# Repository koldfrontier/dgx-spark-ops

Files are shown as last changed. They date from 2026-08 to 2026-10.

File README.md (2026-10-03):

# dgx-spark-ops

Assets, designs and operational notes for running **NVIDIA DGX Spark** / **ASUS Ascent GX10**
desktop AI machines.

## Contents

| Path | What it is |
|---|---|
| [`design/cooling-cage`](design/cooling-cage) | Screwless 3D-printed active-cooling cage for two units, with three 120 mm fans. Print files, CAD source, and a full assembly guide. |
| [`recipes`](recipes) | Reproducible multi-node inference serving configs — launch scripts, boot profiles, tuning data, and honest trust/security notes for specific model checkpoints. Two-, three- and four-node. |
| [`notes`](notes) | Operational findings that outlive any one model: running four Sparks as a switchless RoCE ring, what the topology costs, the failure modes that look like a healthy container, and the re-cabling trap that silently costs a GB10 7/8 of its RDMA bandwidth. |

More to follow.

## Licensing

Code and text in this repository are **Apache-2.0** (see [`LICENSE`](LICENSE)).

3D models are licensed separately as **CC BY 4.0** — see the `LICENSE-CC-BY-4.0.txt` file
alongside the model in question. In short: use, remix and sell derivatives freely, just credit
the source.

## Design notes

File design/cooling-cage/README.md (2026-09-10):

# DGX Spark Dual Cooler

A screwless, 3D-printed active-cooling cage that holds **two DGX Spark / ASUS Ascent GX10**
units on edge and drives three 120 mm fans through them.

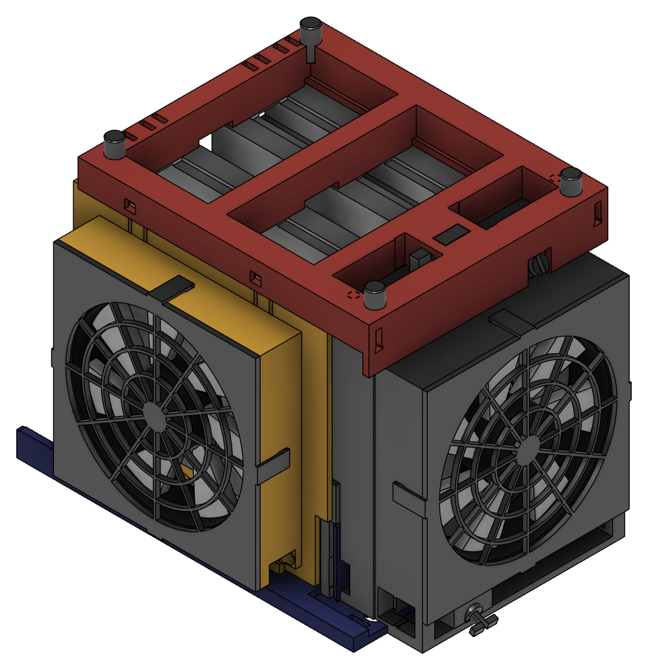
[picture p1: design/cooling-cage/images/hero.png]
Assembled cage


There is not a single screw, heat-set insert or drop of glue in the assembly. Everything
slides into a dovetail, snaps into a latch, clips over a hook, or is locked by one printed
wedge key.

| | |
|---|---|
| Fans | 3 × 120 mm |
| Fasteners | none |
| Assembled size | 206 x 253 x 190 mm |
| Filament | ~580 g PETG at 20 % infill (estimate) |
| Printed parts | 15 (10 unique) |
| Bed needed | 248 × 250 mm (largest part is 176 × 220 mm) |
| Supports | needed on the arm and the plenum; none on the other eight parts |

## How it works

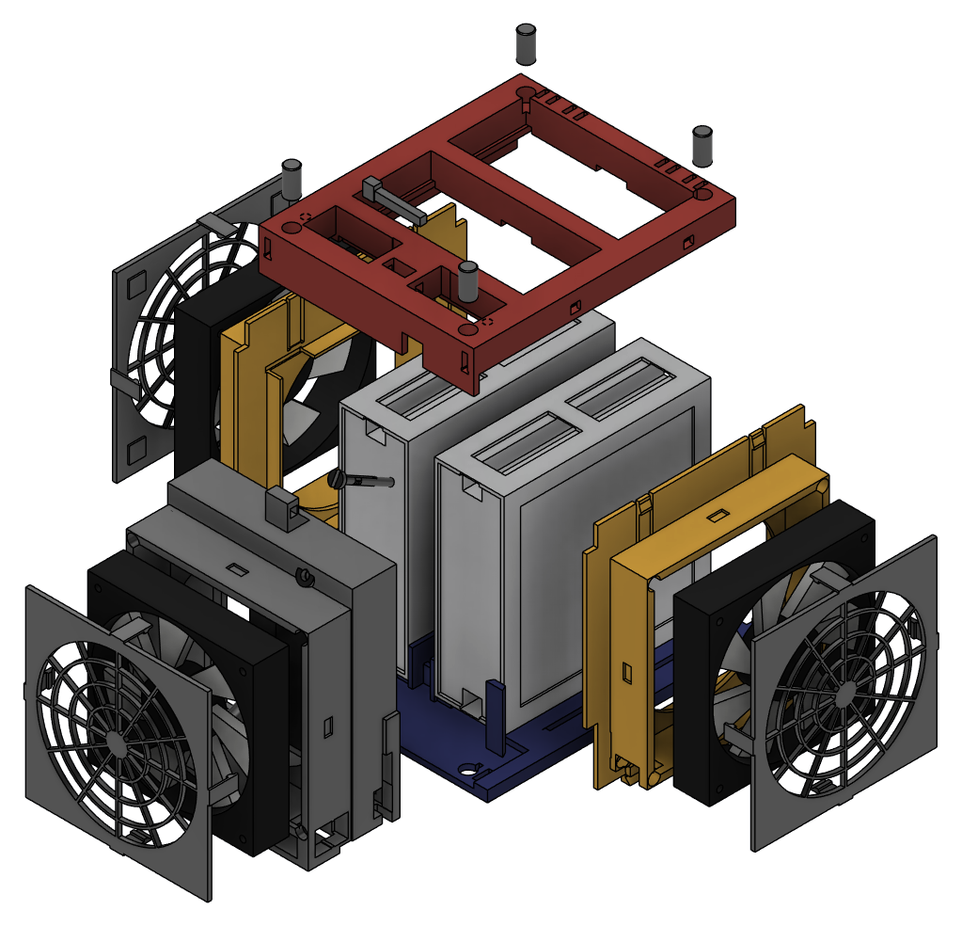
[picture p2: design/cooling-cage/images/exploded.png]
Exploded view


The two units stand on edge and are **mirrored** — one is flipped end-for-end so both filtered
bottom panels face outward into the side fans. Combined width is 50.5 + 19 + 50.5 = 120 mm,
exactly one fan frame.

- **Two side fans** blow inward through each unit's filtered bottom panel.
- **One front fan** pressurises a sealed plenum feeding both front intakes, plus a centre duct
  with two ram scoops that jets air down the 19 mm gap between the units.
- Everything exhausts out the rear, which is deliberately left clear for the port strips, the
  QSFP stacking cable and a future exhaust attachment.

A consequence of mirroring is that one unit's power button ends up near the top of its front
face and the other near the bottom — hence two different captive push-pins.

## Bill of materials

### Printed

| Part | Qty | Size mm | Print orientation | Support |
|---|---|---|---|---|
| `01-base-tray` | 1 | 176 × 220 × 46 | as exported | none |
| `02-front-plenum` | 1 | 139 × 180 × 66 | as exported (back plate down) | **yes** |
| `03-side-fan-arm` | 2 | 171.6 × 166 × 39.6 | as exported (fan collar up) | **yes** |
| `04-top-brace` | 1 | 156 × 190 × 30 | as exported | none |
| `05b-fan-grille-25mm` | 3 | 135 × 135 × 21 | as exported | none |
| `05-fan-grille-26mm` | 3 | 135 × 135 × 21 | as exported | none |
| `06-wedge-key` | 1 | 10 × 6 × 41 | as exported | none |
| `07-stacking-peg` | 4 | Ø10 × 20 | as exported | none |
| `08-button-pin-long` | 1 | 15 × 30.5 × 72.5 | as exported | none |
| `09-button-pin-short` | 1 | 10 × 10 × 46 | as exported | none |

Every STL and the 3MF are already **in their correct print orientation, sitting on Z = 0**.
Drop them in and slice — do not rotate.

**Print only one grille variant.** `05b` has 2.2 mm clamp pads for **25 mm** thick fans;
`05` has 1.2 mm pads for **26 mm** fans. The pads preload the fan against its sealing land, so
the wrong variant leaves the fan loose and buzzing.

### Bought

| Item | Qty | Notes |
|---|---|---|
| 120 mm fan | 3 | Tested with Thermalright TL-C12C (25 mm, 4-pin PWM, ASIN `B0BN19KSW2`, sold as a 3-pack) and NZXT F120 (26 mm). Any standard 120 × 120 fan with a 105 mm hole pitch fits. |
| Fan speed controller | 1 | Wathai 36 W, 110–240 V AC → 4–12 V DC 3 A with a 4-port splitter (ASIN `B0F4KG6MM1`). Voltage control, so all the heat stays in the external brick. Three fans draw ~0.6 A of 3 A. |
| Zip ties | ~8 | 2.5 × 100 mm, for the cable channels |

## Print settings

- **PETG.** Every latch, hook and pin leg is a printed spring; the strain figures assume
  E ≈ 2000 MPa. PLA will work but is more brittle at the flexures.
- **0.4 mm nozzle, 0.2 mm layers.**
- **4 perimeters minimum.** Thin walls halve the strength of every snap feature.
- **20 % infill** is plenty. Nothing is structural beyond the flexures.
- **Supports on for `02-front-plenum` and `03-side-fan-arm`, off for everything else.** Both of
  those parts carry a large flat panel that starts in mid-air, and neither has an orientation
  that avoids it — see [`docs/printability-analysis.md`](docs/printability-analysis.md) for the
  measurements and the six-orientation sweep. Tree supports on the arm's plate underside are
  enough; the plenum wants normal supports under its front face.
- **No brim needed.** The long button pin prints on a 15 × 30.5 mm footprint at 72.5 mm tall.

> An earlier version of this README claimed no part needed support. That was wrong: the v2
> shroud collar removed the arm's only support-free orientation, and the reach figures behind
> the claim did not survive re-measurement. The two large parts need support.

## Fitting the GX10's rubber feet

Foot clearance notches

The GX10 has four rubber feet on its bottom panel, and that panel is the face that looks
outward into the side fans — so the feet land on the shroud collar. The collar's top wall is
notched at both ends to clear them: the top wall runs only over the middle of the span, and the
two end sections are open.

If you are printing from the current files this is already done. If you have arms printed from
an earlier release, cut the top wall away from each collar corner to the far edge of the latch
snap on both sides, at both ends of both arms.

The foot dimensions were never measured — the notch is sized from the collar geometry with
deliberate margin. If a foot still fouls, open an issue with the foot diameter, height and
centre positions.

## Assembly

Full illustrated instructions: **[docs/assembly-guide.pdf](docs/assembly-guide.pdf)** (10 pages).

The short version:

1. Set down the base tray, front edge toward you.
2. Slide both side fan arms in **from the rear** along the 45° dovetails, ~150 mm.
3. Drop the front plenum onto the two dovetail posts.
4. Lower in the two units, mirrored. Connect the QSFP cable now.
5. Push the three fans into their collars from outside — side fans blow **in**, front fan blows
   **rearward**.
6. Clip the three grilles on: line up four hooks each, press until they click (~11 N).
7. Drop the top brace on — the arm latches snap near the end of travel — then tap the wedge key
   home through the bridge and the plenum tenon.
8. Press in the four stacking pegs and snap the two button pins into their tubes.

Teardown is the reverse: drive the key out, release both arm latches, lift the brace.

To swap a fan later, pry off that grille only. Nothing else has to come apart.

## Cable routing

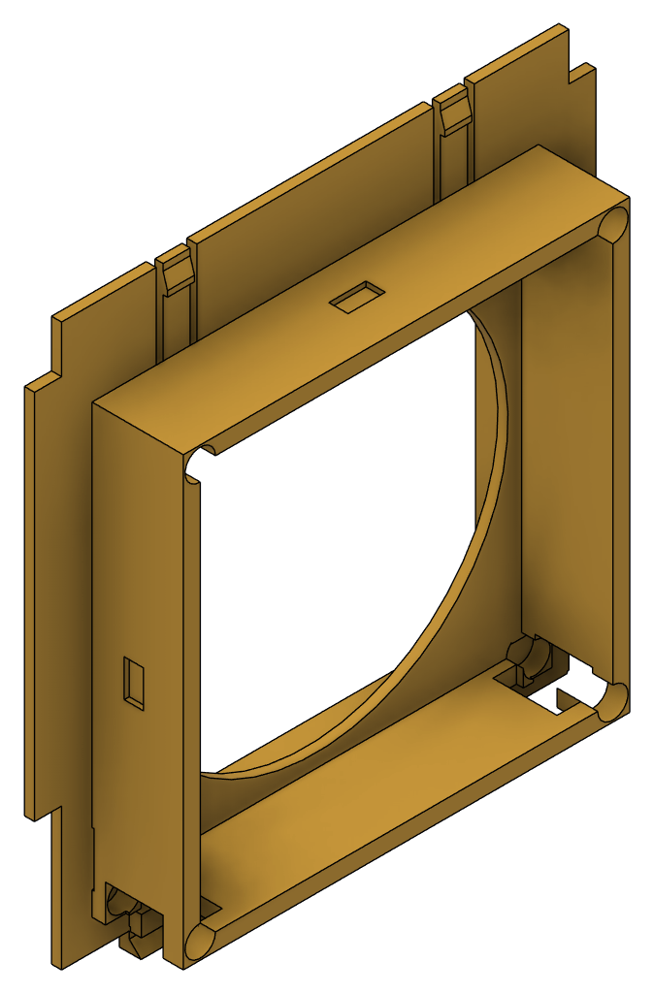
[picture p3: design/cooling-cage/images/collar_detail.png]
Cable routing


All three fan leads run inside the cage and exit together at the rear. Each fan pocket has all
four corners relieved, so whichever corner the lead exits it has a channel; it drops through a
floor exit into the tunnel between the tray ear and the arm collar, then runs rearward through a
gland and out the back of the tray. The front fan's lead exits a side window in the plenum skirt
and joins the same tunnel.

Every restriction on that route passes a 14 × 8 mm fan connector: the arm cable windows are
16.5 × 10.0 mm, the plenum skirt windows 21.5 × 10.0 mm per side, the plenum rear slot
10.5 × 16.5 mm per side, and the fan-pocket floor slots 15.5 mm (arm) and 14.3 mm (plenum).

The run sits entirely outboard of the exhaust footprint and below the port strip, so nothing is
in the hot stream and nothing crosses the rear ports.

**If you add your own bracket to the rear ears, keep it under 17 mm tall** — the arm collar
sweeps that band during assembly, and anything taller makes the arms impossible to fit or remove.

## Files

```
cad/    dgx-spark-cooling-cage.f3d     Fusion source, fully parametric
        dgx-spark-cooling-cage.step    STEP AP214, for any other CAD
print/  dgx-spark-cooling-cage.3mf     all parts, grouped by print plate
        stl/*.stl                      one file per part, print-oriented
docs/   assembly-guide.pdf             10-page illustrated guide
        design-notes.md                engineering rationale and verification
        printability-analysis.md       orientation and support measurements
        v2-tolerance-analysis.md       what the first print got wrong, and by how much
images/                                renders used above
```

The 3MF groups parts into eleven plates. Standard 3MF has no plate concept, so slicers will show
all objects at once laid out in a grid — use "arrange all" or assign plates by hand. The intended
grouping is in `design-notes.md`.

## Status

**v3 — v2's faults fixed in CAD, still unprinted.** The v1 design was printed and assembled;
four problems showed up that CAD had not caught, and all four are fixed:

- the button pin could not be inserted at all (the barb was a full ring that squeezing could not
  shrink — a geometric impossibility, not a tolerance issue)
- the arm latches could not be released (the access window was aimed 1.5 mm above the barb)
- air bypassed the units through a 10 mm gap around each fan discharge
- the units slid side to side, unconstrained outboard above z = 8

Then two more that only turned up later:

- the GX10's rubber feet fouled the shroud collar — the reference model has no feet, so CAD
  never saw it. Notched, see above.
- the collar left the arm with no support-free print orientation, and the plenum had been
  re-oriented onto a worse one. Both re-measured, the plenum re-exported, and the support
  claim in this README corrected.

See [`docs/v2-tolerance-analysis.md`](docs/v2-tolerance-analysis.md) for the measurements behind
the first four fixes. Interference, assembly paths, printability and mesh quality are all
re-verified against the current solids; **nothing since v1 has been printed.**

Two known defects are open: `08-button-pin-long.stl` and `09-button-pin-short.stl` are
non-manifold (a handful of edges shared by four and six faces), which slicers will silently
repair in their own way. The B-reps have not been checked yet.

## License

Models (`cad/`, `print/`, `images/`): **CC BY 4.0** — see
[`LICENSE-CC-BY-4.0.txt`](LICENSE-CC-BY-4.0.txt).
Documentation and code: **Apache-2.0**, per the repository root.

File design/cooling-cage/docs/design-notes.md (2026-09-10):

# Design notes

Engineering rationale, the numbers behind the snap features, and how the design was verified.
Model v33. Everything here was measured against the solid model in Fusion.

**v1 was printed and assembled. Nothing since v1 has been printed** — every figure below for v2
and later is CAD verification, not experience.

## Thermal concept

The units are metal-shelled passive heat spreaders with two internal blowers exhausting rearward,
plus filtered intakes along both long edges of the front face and a filtered intake in the bottom
panel. Standing them on edge exposes the bottom panel to a side fan, which is the largest single
intake either unit has.

- Two side fans blow inward through each unit's filtered bottom panel.
- The front fan pressurises a sealed plenum. Its Ø114 throat opens into the plenum through a 45°
  diffuser chamfer, and two mouth windows feed the units' front intakes.
- A hollow centre duct in the 19 mm gap between the units takes air from two ram scoops sited at
  r = 38–58 mm from the fan axis — inside the blade annulus, clear of the Ø42 hub wake — and
  exits through two 3 × 112 mm slots that jet down each hot inner panel.

The centre duct is a calculated design, not a measured one. Its two exit slots are tapeable, so
an A/B test is easy: tape them, run the same load, compare.

## Fastening

Nothing is screwed. Five mechanisms carry the whole assembly.

| Joint | Mechanism | Numbers |
|---|---|---|
| Arm → tray | 45° half-dovetail, slides in from the rear | 0.12 mm clearance both flanks, 150 mm travel, hard stop at the front |
| Arm → brace | Two cantilever latch barbs into catch pockets | 1.30 mm barb, 0.63 % strain at release, 4.6 N per latch to release, 0.90 mm retained engagement |
| Grille → collar | Four cantilever hooks, 18 × 1.3 × 10 mm, 1.5 mm barb | 1.08 % strain, 2.8 N per hook, ~11 N to click on |
| Plenum → brace | Tusk tenon through a mortise, locked by a wedge key | 0.65 mm of taper available for tightening |
| Button pin → tube | Split shaft, two spring legs, two-pad snap barb | 0.45 mm squeeze needed against 1.20 mm available |

PETG at E ≈ 2000 MPa throughout. Repeated-use strain allowance for PETG is roughly 1.5–2 %, so
every flexure has at least 1.5× margin.

The dovetail clearance, the latch geometry and the pin barb are all v2 values. What they replaced
and why is in [`v2-tolerance-analysis.md`](v2-tolerance-analysis.md) — the v1 pin could not be
inserted at any force, and the v1 latch could not be released at all.

### Button pins

Each unit's front power button is behind the plenum, so each gets a captive printed push-pin
running in a guided tube. Bore profile:

| Distance from mouth | Bore radius | Enclosed |
|---|---|---|
| −0.5 → 2.5 mm | 2.90 mm, with a 38° lead-in funnel | yes |
| 3.0 → 14.0 mm | 4.00 mm (detent chamber) | yes |
| 14.5 mm → end | 2.70 mm | yes |

The barb is **two pads on the outer face of each leg**, limited to |v| ≤ 0.80 mm and crowning at
r = 3.35 — not a revolved ring. That distinction is the whole point: squeezing the legs translates
each half toward the centreline, which retracts material lying along the squeeze axis and does
nothing to material 90° away. A ring cannot be squeezed through its own bore; two pads can.

With the legs fully closed the barb envelope measures 2.159 mm against a 2.90 mm mouth. Required
squeeze is 0.45 mm of the 1.20 mm available, and on a tight printer ≈0.73 mm of 1.10 mm.

Long pin: 20.5° off the button axis, 6.0 mm free stroke, presses at +2.50 mm.
Short pin: 28.7° off axis, 5.0 mm free stroke, presses at +2.25 mm.

## Holding the units still

Each unit is a 150 mm slab. Three constraints hold it:

| Constraint | Position | Where it bears |
|---|---|---|
| Inboard | x = 9.5 (tray centre wall) | z 6–30 |
| Outboard | x = 60.4 (arm shroud collar frame) | y 13.0–15.5 and 135.0–137.5, z 21.0–23.5 and 143.0–145.5 |
| Top corners | x = 60.4 (brace capture ribs) | z 152–158 |

```
left-right play = 60.4 - 9.5 - 50.5 = 0.40 mm
```

Before v2 the outboard face was unconstrained above z = 8 and the unit could slide the full gap
to the arm plate. The shroud collar does double duty here: it is primarily an air seal, and the
lateral datum falls out of it for free.

The collar also cut bypass around each fan discharge from 3 580 mm² to 143 mm², a 96 % reduction.
And it is the reason the arm no longer has a support-free print orientation — see below.

## Clearance for the unit's feet

The GX10 has four rubber feet on its bottom panel, which is the face that looks outward into the
side fans, so the feet land on the collar. The collar's top wall sits 18-20 mm in from the panel
edge while the bottom and side walls sit at 13-15 mm; the feet fall in that 5 mm band and foul
only the top.

The top wall is therefore cut away at both ends, leaving it over y 38.0–112.0 only, mirrored
about y = 75 so both arms clear at both ends. The reference model of the unit has no feet
modelled, which is why interference analysis never caught this.

**The foot dimensions were never measured.** The notch is sized from the collar geometry with
deliberate over-cut, since over-cutting costs nothing here and under-cutting leaves the part
fouling.

## Verification

**Interference.** Full-assembly interference analysis returns three pairs totalling 0.3074 cm³,
all of which are the intended 0.2 mm preload of each grille's four clamp pads against its fan.
No unintended contact anywhere. This figure is the baseline: anything else is a new bug.

**Assembly paths.** Every part stepped along its insertion path with a full interference check at
each step:

| Part | Motion | Result |
|---|---|---|
| Side fan arms ×2 | slide from the rear | clear 150 mm |
| Front plenum | drop −Z | clear 60 mm |
| Units ×2 | drop −Z | clear 60 mm |
| Fans ×3 | push into collar | clear 45 mm each |
| Top brace | drop −Z | clear to 5 mm, then the arm latches cam |
| Wedge key | thread +X | clear 32 mm |
| Grilles ×3 | clip on | clear to 15 mm, then the hooks ride and snap |
| Stacking pegs ×4 | press in | clear to home |

The arms slide in at step 2, before the units drop in at step 4, so the collar never has to sweep
past a seated unit.

**Printability.** Measured as unsupported reach, not overhang area. Eight parts are support-free
with a worst reach of 5.0 mm; the side fan arm and the front plenum both need support and no
orientation avoids it. Full measurements, the six-orientation sweep for the arm, and what the
earlier analysis got wrong are in
[`printability-analysis.md`](printability-analysis.md).

**Mesh quality.** Exported mesh volumes match the CAD solids to within 0.04 cm³ on every part.
**Eight of the ten meshes are watertight and 2-manifold. Two are not:**
`08-button-pin-long` has four edges shared by four faces and two shared by six;
`09-button-pin-short` has eight and eight. That is the coincident-face signature, and both pins
were heavily reworked in v2. Whether the B-reps are non-manifold or only the tessellation has not
been checked. Slicers will repair these silently and by their own rules, which is not what you
want on the one part that already failed once.

## Print plate grouping

The 3MF places every part in a 250 mm grid, one cell per intended plate:

| Plate | Contents |
|---|---|
| 1 | Base tray |
| 2 | Front plenum |
| 3 | Side fan arm (1 of 2) |
| 4 | Side fan arm (2 of 2) |
| 5 | Top brace + wedge key + 4 pegs + both button pins |
| 6–8 | Fan grille ×3, 25 mm variant |
| 9–11 | Fan grille ×3, 26 mm variant (alternate — print one set or the other) |

The grilles are 135 mm square, so only one fits a 248 × 250 mm bed at a time.

## Things that are still open

- **Nothing since v1 has been printed.** Everything above about v2 and later is CAD verification.
- The two non-manifold pin meshes.
- The centre duct's effectiveness is unproven — see the A/B test note above.
- Latch, hook and pin-leg stiffness are calculated, not measured.
- The arm and the plenum need support material. A design fix for the arm — sacrificial ribs or a
  chamfered transition behind the plate — has not been attempted.
- The rear exhaust attachment (routing exhaust to top, left or right while keeping port access)
  is designed for but not built. It must mount to the **top brace**, not the tray ears: nothing
  on the ears may exceed 17 mm in height or the arms cannot be fitted.
- Allow at least 95 mm behind the cage for the QSFP DAC bend radius; 120 mm is comfortable.

## Design rules learned the hard way

Four classes of bug in this project were invisible in the viewport and passed the checks that
were run against them:

1. **Feature order.** Joining material into a region that already has holes through it refills
   those holes. Re-cut any bore after a later join crosses it.
2. **Off-axis features.** Anything whose axis is not a global axis must be built on a
   construction plane perpendicular to *its own* axis. Lofting between global-axis planes
   produces oblique cylinders — elliptical in true section, with smeared shoulders that will not
   retain a snap feature.
3. **Reference geometry is not the real thing.** The unit's reference model has no rubber feet,
   so no amount of interference analysis was ever going to find the collar fouling them.
4. **A fix in one dimension can break another.** The shroud collar solved the air bypass and the
   lateral play at once, and silently removed the arm's only support-free print orientation.

And the general ones: **verify fits by sampling the solid, not by eye** — a missing tube wall that
left a snap pin completely unretained passed every interference check that was run against it.
**And re-measure any result that says a hard part is easy.** The claim that a 13 000 mm² plate
held up by two rails printed support-free stood for two releases.

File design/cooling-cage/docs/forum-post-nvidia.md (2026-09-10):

**Title:** DGX Spark Dual Cooler — screwless modular cage, three 120 mm fans (CAD + files, CC BY 4.0)

---

Two Sparks on a desk generate more heat than one desk wants to deal with, and the stock
orientation makes it worse: sat flat and side by side, each unit's intakes end up either facing
the other unit or facing the desk. I wanted them close enough to keep a QSFP stacking cable short
without one of them breathing the other's exhaust, so I designed an active cage around them and
have been printing and assembling it over the last stretch.

The short version: both units stand **on edge and mirrored** — one flipped end-for-end so both
filtered bottom panels face outward. That matters because the bottom panel is the single largest
intake either unit has, and standing them this way puts a fan directly on it. It also produces a
convenient coincidence: 50.5 + 19 + 50.5 mm of unit and gap is 120 mm, exactly one fan frame, so
the whole cage sizes itself off standard 120 mm hardware.

Three 120 mm fans, and each does something different:

- **Two side fans** blow inward through each unit's filtered bottom panel.
- **One front fan** pressurises a sealed plenum that feeds both front intake strips. Its Ø114
  throat opens into the plenum through a 45° diffuser chamfer rather than a straight step.
- Inside that plenum, a **hollow centre duct** takes air from two ram scoops placed at r = 38–58 mm
  from the fan axis — inside the blade annulus but clear of the Ø42 hub wake — and jets it down the
  19 mm gap between the units through two 3 × 112 mm slots.

That centre duct is the part I'm least certain about. Dead air between two hot inner panels was the
thing I most wanted to eliminate, but the duct is a calculated design, not a measured one. I sized
the scoops to sit in the working part of the blade sweep and left the exit slots deliberately
**tapeable** so an A/B test is trivial: tape them, rerun the same load, compare. If anyone runs
that test I'd genuinely like the numbers, mine or not.

Everything exhausts rearward, and the rear is kept deliberately clear — the port strip, the QSFP
DAC and its bend radius all stay accessible. Allow about 95 mm behind the cage for the cable, 120 mm
is comfortable. All three fan leads are channelled inside the cage and exit together through a
single gland at the back, outboard of the exhaust footprint and below the port strip, so nothing
sits in the hot stream. Every restriction on that route clears a 14 × 8 mm fan connector.

**There is not one screw, heat-set insert or drop of glue in it.** That was a hard constraint, not
a flourish. Anything requiring a hardware kit is something the next person has to source and
mis-order; dovetails, snap latches and one printed wedge key make it reproducible by anyone with a
printer and a spool. Ten unique parts, 15 printed pieces, roughly 580 g of PETG at 20 % infill.
Largest part is 176 × 220 mm, so a 248 × 250 mm bed (P1S and similar) covers it.

On supports: eight of the ten parts print with nothing, worst unsupported reach 5 mm. The side fan
arm and the front plenum both need it. The arm is a 166 × 172 mm plate 3 mm thick with a fan shroud
collar on one face and rails on the other, so the plate cannot touch the bed in any orientation —
I measured all six and the best of them still leaves 2 500 mm² beyond 10 mm of unsupported reach.
Tree supports under the plate handle it and the underside is an internal face. I mention it because
an earlier version of these files claimed no part needed support, which was wrong, and I'd rather
say so than have someone find out on the bed.

PETG specifically, because every latch, hook and pin leg is a printed spring and the strain figures
assume E ≈ 2000 MPa. The flexures run 0.63–1.08 % strain against PETG's ~1.5–2 % repeated-use
allowance, so there's at least 1.5× margin on each. Four perimeters minimum — thin walls halve the
strength of every snap feature in the design.

One consequence of mirroring worth mentioning: the two power buttons end up at opposite ends of the
front face, and both are behind the plenum. Each gets a captive printed push-pin running in a guided
tube, retained by a snap barb so it can't fall out.

One more thing worth flagging for anyone with a GX10 specifically: the four rubber feet on the
bottom panel land on the fan shroud collar, because that panel is the face pointing out into the
side fan. The collar's top wall is notched at both ends to clear them. My reference model of the
unit has no feet on it, so no amount of interference checking was going to find that — it turned
up on the bench.

Files are up — Fusion source, STEP, print-oriented STLs, a 3MF, and a 10-page illustrated assembly
guide, under CC BY 4.0:

**https://github.com/koldfrontier/dgx-spark-ops** → `design/cooling-cage/`

Fan hardware is nothing exotic: any standard 120 × 120 fan with a 105 mm hole pitch fits. I've used
Thermalright TL-C12C (25 mm) and NZXT F120 (26 mm) — there are two grille variants, one per
thickness, and you print whichever matches, since the clamp pads preload the fan against its sealing
land. A cheap AC→DC voltage controller with a 4-port splitter runs all three.

Still open, and where I'd welcome input: the centre duct's real contribution, latch and hook
stiffness in practice versus calculated, whether the arm can be reshaped to print support-free
again, and a rear exhaust attachment to route the outflow up or sideways while keeping port access
— designed for, not yet built. If you print it, please open an issue with what you find.

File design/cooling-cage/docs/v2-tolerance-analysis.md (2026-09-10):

# v2 tolerance analysis and change set

All figures below were measured by ray-sampling the solids in Fusion (model v24), not
read off the drawing. Sampling step 0.05 mm on radii, 0.25–0.5 mm on maps.

---

## 1. Button pin cannot be inserted

> **Corrected.** An earlier version of this document blamed print tolerances. That was wrong.
> Your remark that the dovetail prints *loose* is inconsistent with a tight-printer stack, so I
> went back and tested the geometry directly. The pin cannot be inserted on **any** printer at
> **any** squeeze force. It is a geometric impossibility, not a fit problem.

### Measured, as built

| Feature | Value |
|---|---|
| Bore mouth land radius | **2.70 mm**, s = −1.0 → 3.0 |
| Detent chamber radius | 4.00 mm, s = 3.5 → 13.5 |
| Pin shaft radius | 2.45 mm |
| Barb peak radius | **3.65 mm** at s = 4.5 |
| Barb lead-in ramp | 16.7° |
| Leg slot width | 2.25 mm (half-width 1.125) |
| Leg cantilever length | 17.0 mm |

### Why it cannot work

The barb is a **full revolved ring** of radius 3.65, split by the slot. Squeezing the legs
translates each half toward the centreline — which retracts only the material lying *along*
the squeeze axis. The material 90° away, out near the slot at v ≈ ±3.5, does not move inward
at all; it just slides sideways.

I sampled the barb section (10 700 points) and recomputed its envelope for every squeeze
value up to fully closed:

| Squeeze per side | Barb max radius | Passes the 2.70 bore? |
|---|---|---|
| 0.00 mm | 3.669 | no |
| 0.40 mm | 3.569 | no |
| 0.80 mm | 3.513 | no |
| **1.125 mm (legs touching)** | **3.500** | **no** |

> With the slot **completely shut**, the barb still measures **3.50 mm** where it needs
> 2.70 mm. It is **0.80 mm too big and cannot be made smaller by pressing.** That is exactly
> what you felt: a hard stop that does not respond to force.

The 0.175 mm/side "margin" quoted in the v1 design notes was computed on the u-axis only,
where the barb *does* retract. It never checked the rest of the ring.

### Fix

The barb must project **only in the direction the legs flex**. Replace the revolved ring with
two discrete pads on the outer face of each leg, narrow in v, so that squeezing actually
shrinks the envelope.

| Parameter | v1 | **v2** |
|---|---|---|
| Barb form | revolved ring, 360° | **two pads, ±0.8 mm half-width in v** |
| Barb peak radius | 3.65 | **3.45** |
| Bore mouth land radius | 2.70 | **2.90** |
| Leg slot width | 2.25 | **2.60** |
| Pin shaft radius | 2.45 | **2.60** |
| Mouth lead-in chamfer | none | **0.8 mm × 30°** |

The governing point is now the pad's corner at v = 0.8, not its crown. Required squeeze is
`sqrt(R²−w²) − sqrt(M²−w²)`:

| Printer | Required squeeze | Available | Margin |
|---|---|---|---|
| Nominal | 0.57 mm | 1.30 mm | **0.73 mm** |
| Tight (holes −0.2, posts +0.08) | 0.87 mm | 1.20 mm | **0.33 mm** |
| Loose (holes +0.2, posts −0.08) | 0.28 mm | 1.40 mm | 1.12 mm |

Retention holds across the whole range — worst case 0.27 mm/side of engagement against a
0.016 N gravity load. Strain 0.59 %, insertion ≈ 7 N.

Because the fix works at both ends of the tolerance range, **you do not need to measure
anything.** That was the open question at the end of the v1 document; it is now closed.

---

## 2. Arm latch cannot be released

### Measured, as built

| Feature | Value |
|---|---|
| Arm plate face | x = 73.00 |
| Barb peak | **x = 74.80 at z = 166.00** → protrusion **1.80 mm** |
| Barb ramp | z 172.0 → 166.0, 16.7° |
| Retaining shoulder | z = 165.9 (square drop back to x = 73.00) |
| Tongue slots | y 28.4–29.7 and 38.4–39.7, 1.4 mm wide |
| Tongue | 8.7 mm wide × 3.0 mm thick, root z = 143.5, free end z = 174 |
| Barb distance from root | 22.5 mm |
| **Release window in brace** | **y 31.5–36.75 (5.25), z 167.5–171.5 (4.25), x 75.5–78** |

### Why you can't unlock it

The window exists — but it is aimed at empty air.

> The window spans **z 167.5 → 171.5**. The barb peak is at **z 166.0** and its retaining
> shoulder at **z 165.9**. The bottom edge of the window sits **1.5 mm above the part of the
> barb that has to move.**

Inside the window you can only touch the shallow top of the ramp, where the barb stands
1.35 mm proud instead of 1.80 mm, on a 16.7° slope that cams a flat tool up and out.

Even with a perfect tool, the numbers are bad. Tongue `I = 8.7 × 3.0³/12 = 19.58 mm⁴`.
Pushing at z = 169.5 to move z = 166 by 1.80 mm needs

```
F = 1.80 / 0.11958 = 15.1 N per latch      (2.26 mm of travel at the tool)
```

That is **15 N on each of two latches simultaneously**, while a third hand lifts the brace —
at **1.50 % root strain**, which is the top of PETG's repeated-use allowance. Even if you
could reach it, teardown would craze the tongue roots.

### Fix

Four changes, all on parts you already need to reprint:

| Change | v1 | **v2** |
|---|---|---|
| Window z-span | 167.5–171.5 | **163.5–169.5** (now centred on the barb peak) |
| Window y-span | 31.5–36.75 | **30.5–37.5** (7 mm — fits a 6 mm blade) |
| Barb protrusion | 1.80 | **1.30** |
| Tongue thickness | 3.0 | **2.4** (recess inner face to x = 70.6) |
| Barb top face | 16.7° ramp throughout | **flat push pad, normal to x, z 165.5–167.5** |

Result: **6.6 N per latch, 0.91 % strain**, pushing square on a flat pad you can actually see
and reach. Retention is still ~4× what the joint needs.

---

## 3. Air bypasses around the units

### Measured

Sampling from the DGX side face (x = 60) outward at seven points across the fan opening
found **no arm material at all before x = 70** at six of them.

> The gap between each unit's side panel and the arm plate is **10.0 mm, open on all four
> sides**, across the entire fan discharge.

| | Area |
|---|---|
| Fan bore Ø114 | 10 207 mm² |
| Free bypass path (π × 114 × 10 mm) | **3 580 mm²** |

The bypass path has essentially zero resistance; the intended path goes through the unit's
filtered panel. Air takes the easy route — which is what you are seeing.

### Fix

A **shroud collar on the arm's inner face**, turning the 10 mm open span into a duct:

- Square collar around the Ø114 bore, **124 × 124 mm outer, 2 mm wall**
- Extends from the arm plate at **x = 70 to x = 60.5** (9.5 mm), leaving **0.5 mm** running
  clearance to the unit
- Bypass area drops from 3 580 mm² to **179 mm² — a 95 % reduction**
- Adds ≈ 9.4 cm³ per arm

This is safe for assembly because the arms slide in at step 2, **before** the units drop in at
step 4 — the collar never has to sweep past a unit that is already seated. Printability is
unaffected: the collar walls run parallel to the build direction, no new overhangs.

---

## 4. Units wiggle in the enclosure

### Measured

Tray section at y = 75, tracing what actually touches a unit:

| Side | Support |
|---|---|
| Underneath | rails at z = 8 (the unit's bottom face) |
| Inboard (centre wall) | z = 6 → **30** — 22 mm of a 150 mm-tall unit |
| **Outboard** | z = 6 → **8** — **2 mm** |

Above z = 30 there is nothing on either side. Each unit is a 150 mm slab standing in a 22 mm
socket, open on the outboard face.

> Slop at the top of the centre wall is amplified to the top of the unit by
> `(158 − 8) / (30 − 8) = ` **6.8×**. Half a millimetre of fit clearance becomes **3.4 mm of
> sway** at the top; a millimetre becomes 6.8 mm.

### Fix — two parts, both needed

**A. Capture ribs on the brace underside.** The brace already spans z 150–180 and the units
top out at z = 158, so there is 8 mm of overlap doing nothing. Add ribs forming a **51.5 mm
slot (0.5 mm clearance per side), 6 mm deep, at z 152–158**, straddling each unit's top edge.
This kills the lever arm at the end where all the movement is.

**B. Sprung pads on the arm collar.** Two per arm, at **z = 45 and z = 135**, cantilever
12 × 8 × 1.6 mm with **0.6 mm interference**, pressing the unit inboard against the centre
wall. `F = 5.7 N` each — enough preload to take up clearance without needing a tight fit.

Together these constrain the unit at the bottom (existing rails), the middle (pads) and the
top (ribs), with no screws and no change to the drop-in assembly order.

---

## 5. Dovetail is too loose

You reported the arm-to-tray slide as very loose. The design clearance is **0.30 mm**, which is
generous for a dovetail even on a perfect machine — a 110 mm tongue with 0.3 mm of play will
always rattle. This is a design value, not a printing artefact.

| Parameter | v1 | **v2** |
|---|---|---|
| Dovetail sliding clearance | 0.30 mm | **0.15 mm** |

0.15 mm still slides freely in PETG over 150 mm of travel but takes out most of the play. If
it ends up stiff on your machine, opening it back to 0.20 mm is a one-parameter change.

This is also the only calibration datum available, and it is worth stating what it does and
does not tell us: a loose dovetail rules out a printer running *tight*, which is what sent me
back to re-check §1. It does not pin down the exact offset, which is why the §1 fix above is
sized to work across the full tolerance range rather than at one assumed value.

---

# Verification — all five changes applied and measured

Model saved as **v25**. Every number below was re-measured from the modified solids, not
predicted.

## 1. Pin insertion — was impossible, now passes

The barb is now two pads limited to **|v| ≤ 0.80 mm**, crown **r = 3.35** with a flat land over
s 4.5–5.5, lead-in ramp unchanged at 16.7°. Bore mouth opened to **r = 2.90** with a 38° funnel.

Re-running the same squeeze simulation that condemned the old design:

| | v1 | **v2** |
|---|---|---|
| Barb radius, legs fully closed | 3.500 mm | **2.159 mm** |
| Mouth radius | 2.70 mm | **2.90 mm** |
| Squeeze needed to clear | impossible | **0.45 mm** |
| Squeeze available | 1.125 mm | **1.20 mm** |
| Margin | −0.80 mm (hard stop) | **+0.75 mm** |

Engagement at rest is 0.45 mm per side against a 0.016 N load. On a tight printer the required
squeeze rises to ≈0.73 mm against 1.10 mm available — still passes.

## 2. Latch release — was unreachable, now a flat pad in the open

| | v1 | **v2** |
|---|---|---|
| Barb protrusion | 1.80 mm | **1.30 mm** |
| Contact surface | 16.7° ramp (cams tool out) | **flat pad, z 166.0–167.5, normal to x** |
| Window z-span | 167.5–171.5 (above the barb) | **163.5–171.5** |
| Window y-span | 5.25 mm | **7.0 mm** |
| Tongue thickness | 3.0 mm | **2.4 mm** |
| Straight-line access to pad | none | **clear, z 166.25–171.75** |
| Release force | 15.1 N per latch | **4.6 N per latch** |
| Root strain at release | 1.50 % (at PETG limit) | **0.63 %** |
| Retention engagement | 1.30 mm | **0.90 mm** |

Cutting the window initially removed the catch lip — engagement went to zero. Caught it on the
verification scan and restored the lip; it now measures 0.90 mm on all four latches.

## 3. Bypass — shroud collar fitted

124 × 124 mm square collar, 2 mm wall, from the arm plate at x = 70 out to **x = 60.4**,
leaving 0.4 mm running clearance to the unit.

| | v1 | **v2** |
|---|---|---|
| Bypass area | 3 580 mm² | **143 mm²** |
| Reduction | — | **96 %** |
| Arm volume | 115.5 cm³ | 124.9 cm³ |

## 4. Unit retention — corrected after your feedback

My first pass assumed the units were **rocking** about their base, which is why I raised the
tray centre walls from z 30 to z 52 — tall inboard support shortens the lever arm. You corrected
that: the units slide **left to right**, and rib height is irrelevant.

That changes the answer. A rigid box resting on flat rails translates sideways; it does not need
tall support to be stopped, only a positive stop at any height. The added rib height bought
nothing and cost duct flow, so it is **removed** — the centre walls are back to z = 30 and the
centre channel is full 19 mm again over its whole height.

What actually stops the sideways motion is the shroud collar from §3, which turned out to do
double duty:

| Constraint | Position | Where it bears |
|---|---|---|
| Outboard | **x = 60.4** (collar frame) | rectangular frame on the unit's side panel: y 13.0–15.5 and 135.0–137.5, z 21.0–23.5 and 143.0–145.5 |
| Inboard | **x = 9.5** (tray centre wall) | z 6–30 |
| Top corners | x = 60.4 (brace ribs) | z 152–158 |

```
left-right play = 60.4 - 9.5 - 50.5 = 0.40 mm
```

Before v2 the outboard face was unconstrained above z = 8, so the unit could slide the full
gap to the arm plate. **0.40 mm** is what remains, set by the collar's running clearance.

If 0.40 mm still reads as loose in the hand, the lever is that clearance and nothing else —
taking the collar to x = 60.25 halves it. I left it at 0.40 because the unit has to drop 150 mm
past that frame during assembly and a tighter running fit risks scraping.

## 5. Dovetail — tightened

| Flank | v1 | **v2** |
|---|---|---|
| Inboard vertical | 0.30 mm | **0.12 mm** |
| 45° dovetail face | 0.28 mm normal | **0.12 mm normal** |

## Whole-assembly checks

| Check | Result |
|---|---|
| Interference, 20 occurrences | **3 pairs, 0.3074 cm³** — identical to baseline, all intended grille preload |
| Arm 1 slide −Y | clear over 150 mm |
| Arm 2 slide +Y | clear over 150 mm |
| Plenum drop | clear over 60 mm |
| Both units drop | clear over 60 mm |
| Top brace drop | clear over 40 mm |
| Printability, 6-direction sweep | every part support-free; **worst bridge 10.87 mm** (was 12.8) |

No new interference anywhere, and no assembly path regressed.

## Still outstanding

- **Print files regenerated.** As of model **v33** the STLs, the 3MF, the STEP and the f3d in
  `print/` and `cad/` are all exported from the current solids. The STEP was additionally found
  to have been incomplete in every previous release — Fusion's STEP export only writes visible
  occurrences, and only three or four of the ten parts happened to be switched on. It now carries
  all ten.
- The centre duct is back to a full 19 mm channel over its whole height — the ribs that would
  have narrowed it are gone, so the tape A/B test is unaffected by v2.

## What v2 did not catch

Two faults survived this analysis and were found later. Both are documented elsewhere; they are
listed here because they belong to the v2 change set.

**The shroud collar fouls the unit's rubber feet.** The GX10 has four feet on its bottom panel,
which is the face that looks outward into the side fans. The reference model has no feet, so
interference analysis could not see it. The collar's top wall now stops short at both ends,
leaving material only over y 38.0-112.0. See the README and `design-notes.md`.

**The shroud collar removed the arm's support-free print orientation.** In v1 the arm plate went
straight onto the bed with its rails pointing up. The collar put 9.6 mm of structure on the other
face, so the plate can no longer touch the bed in any orientation, and it is a 13 000 mm² panel
carried by two narrow rails. The v2 printability pass reported this as 25 mm² beyond 10 mm reach;
re-measured it is 4 156 mm². The same pass moved the plenum onto a worse orientation on a
prediction that also did not hold. Both are re-measured in `printability-analysis.md`; the plenum
has been re-exported and the arm now ships with support documented.

The pattern in both is the same one §1 of this document was written about: a number that made a
hard problem look easy, taken at face value.

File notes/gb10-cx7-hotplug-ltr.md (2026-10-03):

# A re-cabled DGX Spark can lose 7/8 of its RDMA bandwidth until reboot

Found while re-cabling three GB10 units (ASUS Ascent GX10, DGX OS kernel `6.17.0-1032-nvidia`, CX7
firmware `28.45.4028`) from a four-node ring into a three-node triangle, 2026-10-03. Measured, with the
method below; the mechanism is inferred, and the note says where.

## Symptom

A tensor-parallel model prefilled 35-45% below its published numbers on two and on three nodes, while
decode was only ~10% low. Every usual check passed: links up at 200 Gb/s, PCIe Gen5 x4, MTU 6000 /
`active_mtu` 4096, RDMA counters moving on both rails of every cable, nothing on the LAN.

## What perftest showed

`ib_write_bw` (1 MiB, 4 s) and `ib_write_lat` (8 B), model stopped:

| | bandwidth a rail | latency |
|---|---:|---:|
| cable between two re-plugged nodes, either direction | 13.1-13.3 Gb/s | 1.4 us |
| cable from a node that kept a cable in throughout | 109.3 Gb/s | 1.4 us |
| **loopback on one device of a re-plugged node** (never leaves it) | **14.2 Gb/s** | |
| loopback on the node that kept a cable in | 106.7 Gb/s | |
| every cable and loopback after rebooting the re-plugged nodes | 106.4-109.3 Gb/s | 1.4 us |

The loopback result puts it on the host side, not the cable: every RDMA transfer that **reads host
memory** on the affected node runs at ~1/8 speed. Latency is untouched - which is why decode (small,
latency-bound all-gathers) barely shows it and prefill (bulk all-gathers) does.

## What differs on an affected node

GB10 hot-removes the ConnectX-7 from PCIe when **both** QSFP cages are empty (`cx7-pcie-hotplug ...
Cable removal` in `dmesg`) and re-adds it on the next plug-in (`Cable plugin`). Diffing `lspci -vvv` of
the CX7 functions and their root ports against an unaffected node, the one functional difference:

| node | hotplug events during the re-cable | root ports' `DevCtl2` | loopback |
|---|---|---|---:|
| kept a cable in throughout | none | `0x0420` (LTR Mechanism Enable on) | 107 Gb/s |
| cables removed, CX7 still absent | `Cable removal` only | `0x0420` | - |
| cables removed and re-plugged (x2 nodes) | `Cable removal` + `Cable plugin` | **`0x0020` (LTR off)** | 14 Gb/s |

Everything else matched: PCIe link (Gen5 x4), MaxPayload / MaxReadReq 512, relaxed ordering, IOMMU mode
(`DMA-FQ`), pause settings, firmware, kernel. (The surprise removal also leaves sticky `SDES+` /
`FatalErr+` status bits, which change nothing.)

**Proven:** a reboot restores both the LTR bit and full bandwidth (two nodes, before/after above).
**Not proven:** that LTR is the mechanism. We could not set the bit alone: kernel lockdown under Secure
Boot refuses `setpci` writes ("Operation not permitted"). Treat LTR-off as the reliable *marker* of the
bad state.

## Check and avoid

```bash
# on each node: 0420 is healthy, 0020 means "reboot me"
sudo setpci -s 0000:00:00.0 CAP_EXP+28.w; sudo setpci -s 0002:00:00.0 CAP_EXP+28.w
dmesg | grep cx7-pcie-hotplug        # "Cable plugin" since boot = suspect
```

or run [`../recipes/GLM-5.3-Flash-EXL3-TensorFold-Triple-DGX-Sparks/fabric/check-fabric.sh`](../recipes/GLM-5.3-Flash-EXL3-TensorFold-Triple-DGX-Sparks/fabric/check-fabric.sh),
which also does a 3 s loopback `ib_write_bw` on every addressed device.

- **Re-cable one cable at a time**, so no node ever has both cages empty; or
- **reboot every node that logged `Cable plugin`** before you measure or serve.

## A second trap when you re-address after a re-cable

On DGX OS the CX7 ports are NetworkManager profiles generated from netplan. If you re-address them at
runtime (`ip addr`), **any carrier change - a peer rebooting, a re-plug - makes NetworkManager re-apply
the saved profile**, addresses and static routes, on both ends of the cable. A profile with
`ipv4.method=link-local` also re-adds a `169.254.x.x` address whenever it is removed; NCCL's bootstrap
takes the first IPv4 of `NCCL_SOCKET_IFNAME`, so a two-node start then fails with `connect to
169.254.x.x ... Network is unreachable` -> `NCCL error 2: unhandled system error`. Either write the new
topology into netplan, or set the ports `unmanaged` for the session (`nmcli device set <dev> managed no`;
a reboot undoes it).

## What it cost, for scale

GLM-5.3-Flash (EXL3 4 bpw, TensorFold), same recipe and checkpoint, before and after the reboots:

| | affected | after reboot |
|---|---:|---:|
| three nodes: prefill ~8K / ~32K tok/s | 1,181 / 1,188 | 2,205 / 2,231 |
| three nodes: one-stream prose / code tok/s | 57.6 / 87.2 | 62.8 / 99.3 |
| two nodes: prefill ~8K / ~32K tok/s | 1,375 / 1,406 | 1,921 / 1,966 |

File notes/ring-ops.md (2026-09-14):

# Running four DGX Sparks as a switchless ring

Operational notes from a four-node GB10 cluster wired as a cycle — each unit's
two QSFP ports cabled to its two neighbours, no switch — serving one
tensor-parallel vLLM workload. Everything below is measured on that hardware
unless it says otherwise, with the method included so you can judge whether it
transfers.

Companion to [`../recipes/DeepSeek-V4.1-Flash-Quad-DGX-Sparks`](../recipes/DeepSeek-V4.1-Flash-Quad-DGX-Sparks),
which is the serving config these notes came out of.

---

## 1. Verify the transport by counters, not by config

The single most useful habit on this hardware. NCCL will silently fall back to
TCP over your management network and everything still works — just slowly, in a
way that looks like a GPU or a model problem for hours.

```bash
# before and after one real generation, on every node
for d in /sys/class/infiniband/roce*; do
  echo "$(basename $d) xmit=$(cat $d/ports/1/counters/port_xmit_data)"
done
cat /sys/class/net/<fabric-if>/statistics/tx_bytes
```

IB counters are in units of 4 bytes. If `port_xmit_data` does not move across a
generation, **NCCL is not using RDMA**, whatever the config says. On this
cluster that fallback survived a full four-node reboot, cable swaps, checkpoint
byte-verification and image-immutability checks, because none of those touch
container device access. Fixing it took an 8-stream benchmark from 48.57 to
85.66 tok/s.

Two things make the failure loud instead of silent:

- `NCCL_NET=IB` — the fallback becomes `NET/IB : No device found` at startup.
- Give the container `--cap-add IPC_LOCK --device /dev/infiniband:/dev/infiniband`
  and `--ulimit memlock=-1:-1`. (`--privileged` also works and is what we used
  first; the narrower pair is enough.)

Healthy startup lines look like `NET/IB : Using [0]<hca>:1/RoCE` and
`Channel 00/04` … with `Tree transport setup disabled` on a ring-only build.

## 2. The RoCEv2 GID index is per machine. Derive it, never copy it

Identical units, same model, same day, gave GID index **3** on two nodes and
**5** on the other two. The index you want is the one that is both an IPv4
RoCEv2 entry *and* carries that node's fabric address:

```bash
for i in $(seq 0 15); do
  g=$(cat /sys/class/infiniband/<hca>/ports/1/gids/$i)
  t=$(cat /sys/class/infiniband/<hca>/ports/1/gid_attrs/types/$i 2>/dev/null)
  echo "$i $g $t"
done | grep -i 'ffff.*RoCE v2'
```

Wire it into a preflight that refuses the boot rather than a comment in a
runbook — a wrong GID index does not fail cleanly, it produces connection
attempts that hang or fall back.

## 3. Cabling: prove the cycle before you configure it

Cable labels lie and ports are easy to swap. Confirm the neighbour on each
port with LLDP (`lldpctl`, or `tcpdump -i <if> -s0 ether proto 0x88cc`) and
write the cycle down. Everything downstream — the rank map, which HCA faces
which neighbour, the routes — is derived from that one fact, and a transposed
pair produces a fabric that links, passes `ping`, and then performs oddly under
collectives.

## 4. Routing on a cycle: two nodes forward, two do not

On a ring, non-adjacent nodes have no direct link. NCCL does not need one (see
§6), but everything else does — the NFS share, the rendezvous, your own SSH.
The arrangement that works:

- One /24 per link, both endpoints addressed in it.
- Two opposite nodes enable `ip_forward` (and an `ACCEPT` rule in Docker's
  `DOCKER-USER` chain, or Docker's default `FORWARD` drop silently breaks
  transit traffic *only* — which is a confusing way to find out).
- Static routes on every node for the two subnets it cannot reach directly.
- `nofail,_netdev` on the share's fstab entry, or a worker that boots before
  the head simply has no checkpoint and the launcher's preflight has to mount
  it.

**Keep a second, always-up control plane** (a VPN/tailnet address per node).
Being able to boot the cluster with `CTRL=private` before the fabric routes
exist — and to fix the routes remotely when they do not — is worth the extra
interface. Our launcher takes `CTRL=private|fabric` for exactly this.

## 5. What the ring topology actually costs

Measured with the DSv4.1-Flash TP4 workload described in the recipe.

**Decode: the fabric is latency, not bandwidth.**

| | |
|---|---:|
| all-reduce p50, 8 KB | 41.7 µs |
| all-reduce p50, 60 KB | 59.0 µs |
| all-reduce p50, 1 MB | 175.9 µs |
| 88 all-reduces back-to-back (one decode step's worth) | 4.64 ms |
| decode step time | 62–67 ms |

So the whole fabric is **~7% of a decode step**, and most of those 42 µs is
NCCL software (proxy thread, protocol, launch), not wire time — an 8 KB
all-reduce is under 4 µs of wire at 100 Gb/s. No topology change can give back
more than that 7%, and a faster link gives back almost none of it.

**Prefill: bandwidth matters, bounded.** Reading the head's HCA counters around
one cold 130,258-token prompt (88.4 s to first token):

- 181.5 GB transmitted = **1.39 MB of fabric traffic per prompt token**
- = 2.85 GB per 2,048-token scheduler step
- = 228 ms of wire time in a 1,390 ms step at ~100 Gb/s → **16% of prefill**
- and the link averaged only 16 Gb/s over the prompt: it is bursty between
  compute phases, not saturated.

**Steady state.** Over a 20-minute 8-stream soak each ring link carried 531.1 GB
in its forward direction (and 4.7 GB back — see §7), all four links within
0.1 GB of each other. That equality is a useful balance check: a link that moved
materially less is a link that is not carrying its share of the ring.

**Pinned shared memory.** Under the ring-only patch with 4 channels and no
buffer tuning, NCCL's pinned `Shmem` footprint is 0.35–0.37 GiB per node. For
comparison, MiaAI-Lab measured NCCL's default connection buffers at 4.7 GiB per
node on GB10 before tuning. Two peers per rank and no Tree appears to avoid
that bloat structurally, which matters when 128 GB is shared between host and
GPU.

## 6. Why a ring is not slower than a switch here (and when it would be)

The common objection: on a switch every rank has a full-rate path to every
other rank; on a ring each rank talks only to two neighbours at half the
aggregate injection bandwidth. True, and it mostly does not matter for
tensor-parallel serving:

- **TP does all-reduce and all-gather only.** NCCL's ring algorithm sends every
  byte one hop to a neighbour; rank 0 never needs to reach rank 2. The missing
  direct links carry no traffic even when they exist.
- **Decode is latency-bound** (§5). A switch lets stock NCCL use Tree/PAT
  instead of Ring, which for four ranks is a latency trick worth a fraction of
  4.64 ms in a 63 ms step.
- **Prefill is the only place a wider pipe shows up**, and it is 16% of the
  step, so the ceiling is single digits end to end.

Where a switch does win: **more than four nodes** (a ring's hop count grows,
a star's does not), any-to-any collectives (expert parallel, all-to-all),
pipeline-parallel layouts, resilience (one dead cable takes down a ring, not a
star), and running stock NCCL instead of a patched build. Those are the reasons
to buy one — mostly not tok/s.

The one concrete tok/s exception so far: tonyd2wild's speed run measured a
**one-shot RoCE all-reduce** (local-inference-lab's b12x, replacing NCCL for
small collectives) at code +11% / prose +16% single-stream on a switched
four-Spark fleet. It is an all-to-all RDMA write on one HCA, so a ring cannot
run it. If you are choosing between the topologies for a TP4 decode workload,
that ~10% is the number to weigh against the ring's simplicity.

**Channel count.** `NCCL_MAX_NCHANNELS=8` (from the same speed run, +10.7% C6
on a switch) measured neutral on the cycle as its own boot: C6 +1.4%, decode
step and prefill inside run-to-run noise, NCCL's pinned `Shmem` on the head
0.48 -> 0.62 GiB. The ring-only build's 4 channels stay.

If you do move to a switch, RoCE on a small managed switch wants **lossy mode
with QoS off**, not the lossless-PFC setup datacenter documentation assumes;
several DGX Spark deployments have collapsed to single-digit Gb/s with clean
links and zero loss until PFC was disabled on both switch and hosts.

## 7. A ring runs one direction (an open question)

On our four-rank cycle, **every channel uses the same orientation**: each rank
transmits on one HCA and receives on the other, and the reverse direction
carries only control traffic. IB counter deltas over a 1,289 s eight-stream
soak:

| rank | HCA A xmit / rcv (GB) | HCA B xmit / rcv (GB) |
|---|---:|---:|
| 0 | 531.1 / 4.7 | 4.7 / 531.1 |
| 1 | 4.7 / 531.1 | 531.2 / 4.7 |
| 2 | 531.1 / 4.6 | 4.7 / 531.2 |
| 3 | 4.6 / 531.1 | 531.1 / 4.7 |

Stock NCCL duplicates channels with the two NICs' roles swapped, which on a
cycle is the reverse orientation. If channels could alternate, the same bytes
would leave over both ports, halving the 16% prefill wire share — an upper
bound of ~8% on cold long prompts, nothing on decode, with the cables you
already have. Whether that is deliberate (peer/GID advertisement, deadlock
avoidance) or an artefact of how the cycle builder duplicates channel 0 is
asked upstream in
[sparkring#273](https://github.com/FujitsuPolycom/sparkring/issues/273).

## 8. Failure modes that do not announce themselves

These cost us the most time; all four look like a healthy `docker ps`.

**A patch set built against the wrong commit.** Whole-file Python patches over
a tree that moved: loads fine, boots fine, every generation is garbage. The
patched file was consistent with the file *next to* it in the old tree, and an
upstream commit changed that neighbour. Pin the commit by sha, and verify by
hashing an **unpatched** file that the patch set depends on — the neighbour,
not the patch — inside the built image. A *newer* file
over an older tree usually crashes (loud, fine); an *older* file over a newer
tree boots and is wrong (silent, expensive).

**A CUDA-graph capture list that never matches.** With speculation on, a decode
step's batch is `k` or `k+1` tokens per sequence, so the capture list must be
the multiples of those up to your max sequences (at k=5, 8 seqs:
`5,6,10,12,15,18,20,24,25,30,35,36,40,42,48`). A hand-written list like `[8]`
forces the engine to pad into an uncaptured shape and yields silent NaN, not an
error. Derive the list in the launcher; never type it.

**Orphaned engine workers.** `pkill -f 'vllm serve'` kills the launcher, not
the `EngineCore` / `Worker_TP*` children — vLLM renames those process titles.
They keep the GPU and the port and contend with the next boot. Kill by PID and
confirm `nvidia-smi` shows no compute process before relaunching.

**Launch order.** Start the headless workers first and the head (rank 0) last;
stop in the opposite order, head first. Launching rank 0 first "works" and then
produces a reproducible ~40% throughput regression that survives a reboot and
looks like a hardware mystery. A worker joining a still-listening old head
hangs the boot outright.

## 9. Benchmarks that mislead on this stack

- **A single prompt's tok/s means little without its acceptance length.** Our
  per-category C1 spread in one run is 30.6 (narrative) to 90.5 (counting) —
  3× on one engine — and it tracks speculative acceptance. Compare like with
  like, or compare `ms/step` and `tokens/step` separately.
- **The KV pool is a lottery, not a setting.** Four boots of an identical
  config gave 1,109,543 / 1,140,181 / 1,287,900 / 1,350,412 tokens, because the
  pool is computed from free memory at init and that depends on host state. One
  boot per arm cannot attribute a pool difference to a flag. Tune for headroom;
  gate on step time.
- **`expandable_segments:True` vs `False`.** Another fleet reported a large KV
  gain from `False`; A/B'd here it cost **19–37% decode throughput**, and its
  apparent KV gain did not survive a third boot. Measure allocator flags on
  step time, not on the pool.
- **Prefix caching makes prefill cells lie.** Two bench runs in the same
  process with the same seeds will hit the cache on the second; a cold-prefill
  cell that suddenly reads 3× faster (or, once, 2× slower on a first-use JIT
  compile) is an artefact. Use unique random prefixes.
- **`hangcheck`-style log watchers false-positive on long prefills.** vLLM adds
  prompt tokens to its throughput log only when the first output token appears,
  so a cold 300K prefill logs `prompt throughput 0.0 / generation ~0 tok/s` for
  minutes with every GPU busy. Watch `vllm:kv_cache_usage_perc` creeping up
  instead.

## 10. Housekeeping that turned out to matter

- **Caches off `/tmp`.** `/tmp` and `/var/tmp` are wiped on reboot on a stock
  DGX Spark; a wiped Triton/FlashInfer cache costs minutes of JIT on the first
  request after every boot. Put `VLLM_CACHE_ROOT`, `TRITON_CACHE_DIR` and
  friends under the user's home and bind-mount them.
- **Drop the page cache before a big load** (`sync; echo 3 > drop_caches`) and
  refuse to boot below a `MemAvailable` floor. On unified memory, the page
  cache is competing with the model.
- **Check `/proc/buddyinfo` after long uptime** — memory fragmentation makes a
  large contiguous allocation fail in ways that read as an OOM.
- **`--restart no`, always.** A four-node TP workload cannot self-heal one
  rank; an automatic restart produces a rank that boots into a dead rendezvous
  and holds the GPU.
- **`--oom-score-adj 500` on the engine** so the kernel kills it before it
  kills sshd — and then never build an image on a node that is serving.

---

*Measured on four GB10 units (DGX Spark / ASUS Ascent GX10) on a switchless
RoCE cycle, 2026-09. Numbers are from the workload in the companion recipe; the
method is given so you can re-run them rather than take them on faith.*

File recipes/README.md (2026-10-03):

# Recipes

Reproducible serving configs for specific model checkpoints on **DGX Spark /
ASUS Ascent GX10** clusters — two nodes or four. Each recipe is a standalone
directory:
launch scripts, what's genericized vs. what you need to fill in for your own
hardware, trust notes on any third-party image or toolkit involved, and
honest tuning/benchmark data from the hardware it was developed on — not
vendor claims taken at face value.

| Recipe | Checkpoint | Notes |
|---|---|---|
| [`SuperDeepseek-V4-Flash-abliterated-MQ-Dual-DGX-Sparks`](SuperDeepseek-V4-Flash-abliterated-MQ-Dual-DGX-Sparks) | [`Jiunsong/SuperDeepseek-V4-Flash-abliterated-MQ-2xDGX`](https://huggingface.co/Jiunsong/SuperDeepseek-V4-Flash-abliterated-MQ-2xDGX) | 304B-class MoE, 1M context, checkpoint author's forked vLLM runtime |
| [`Qwen3.8-Flash-Next-FP8-Dual-DGX-Sparks`](Qwen3.8-Flash-Next-FP8-Dual-DGX-Sparks) | [`Qwen/Qwen3.8-Flash-Next-FP8`](https://huggingface.co/Qwen/Qwen3.8-Flash-Next-FP8) | Native FP8, MTP speculative decoding, vision, 262K context |
| [`DeepSeek-V4.1-Flash-Quad-DGX-Sparks`](DeepSeek-V4.1-Flash-Quad-DGX-Sparks) | [`deepseek-ai/DeepSeek-V4.1-Flash`](https://huggingface.co/deepseek-ai/DeepSeek-V4.1-Flash) | **Four** nodes on a switchless ring — no switch required. 300K / 500K / 1M context, DSpark speculation, vision + tools, boot profiles, Engram fast staging |
| [`GLM-5.3-Flash-EXL3-TensorFold-Triple-DGX-Sparks`](GLM-5.3-Flash-EXL3-TensorFold-Triple-DGX-Sparks) | [`Mia-AiLab/GLM-5.3-Flash-EXL3-4bpw-TensorFold`](https://huggingface.co/Mia-AiLab/GLM-5.3-Flash-EXL3-4bpw-TensorFold) | Three nodes as a switchless triangle on MiaAI-Lab's TensorFold recipe v1.5; fabric health check; three measured speed settings, a noise-aware map of what does not help, a per-rank profile, two optional engine patches |

## Conventions across recipes

- **Nothing in a recipe's example values (IPs, hostnames, NIC names) should
  be copied verbatim.** They describe the hardware a recipe was developed
  and measured on. Each recipe's own "Finding your own values" section
  explains what to check on your hardware instead, and why.
- **Benchmarks are from the hardware they were run on, not vendor
  marketing.** Where a recipe cites a throughput number, it says whether
  that number is a vendor claim, a reproduction of one, or an independent
  measurement — and includes enough method (concurrency levels, prompt
  sizes, what `/metrics` showed) to judge whether it transfers to your
  setup.
- **Third-party images and toolkits are trust-checked, not just used.**
  Each recipe that depends on one says what was checked (stars, account
  age, layer history, documented-vs-actual behavior) and where that trust
  bar is thin.
- **Security tradeoffs are stated, not silently made for you.** If a recipe
  binds an API to something broader than a private network by default, it
  says so and tells you how to tighten it.
- **Each recipe says when it was last verified**, and on what. A recipe whose
  hardware has since been repurposed still tells you what it did on the day it
  was measured — it just does not pretend that was this morning.

Topology-level findings that are not specific to one checkpoint live in
[`../notes`](../notes).

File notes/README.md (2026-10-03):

# Notes

Operational findings from running these machines, separate from any one
model's recipe. Measurements are from our own hardware with the method
included; where something is inferred rather than measured, it says so.

| Note | What it covers |
|---|---|
| [`ring-ops.md`](ring-ops.md) | Four DGX Sparks as a switchless RoCE ring: verifying the transport by counters, per-node GID derivation, cabling and routing on a cycle, what the topology costs (4.64 ms of a 63 ms decode step; 16% of prefill), ring vs switch, and the failure modes that look like a healthy container |
| [`gb10-cx7-hotplug-ltr.md`](gb10-cx7-hotplug-ltr.md) | Re-cabling a GB10 so both QSFP cages are empty leaves its ConnectX-7 at ~1/8 RDMA bandwidth until reboot (the root ports' LTR bit as the marker, loopback `ib_write_bw` 14 vs 107 Gb/s), how to check and avoid it, and NetworkManager undoing runtime fabric addresses |

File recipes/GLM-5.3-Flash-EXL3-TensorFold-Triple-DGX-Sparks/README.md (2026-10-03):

# GLM-5.3-Flash EXL3 · three DGX Sparks, TensorFold, no switch

Serves [`Mia-AiLab/GLM-5.3-Flash-EXL3-4bpw-TensorFold`](https://huggingface.co/Mia-AiLab/GLM-5.3-Flash-EXL3-4bpw-TensorFold)
as one OpenAI-compatible endpoint, tensor-parallel across **three** DGX Spark / ASUS Ascent GX10 units
cabled as a **triangle** (one direct QSFP cable per pair, no switch), using
[MiaAI-Lab's TensorFold recipe](https://github.com/MiaAI-Lab/GLM-5.3-Flash-EXL3-2x-DGX-Sparks-TensorFold)
v1.5 and its experimental three-Spark engine.

This directory is not a fork of that recipe. It is what we add on top to run it well on three nodes: the
fabric setup and a check that catches a silently degraded fabric, three start settings measured to help,
a measured map of the settings that do not, a per-rank profile of where the time goes, two optional engine
patches, the harness and every result.

| | |
|---|---|
| Shape | TP3 across 3 x GB10, rank 0 serves the API on `:8888`, 8 requests at once |
| Engine | TensorFold v0.6.0 + recipe v1.5 (`1576746`, 70 patches), image `v0.6.0-9f73cca659a1` |
| Checkpoint | `078455ff`, 164 GiB, one copy on the head, read by the workers over NFS |
| Start line | `COMM=roce ./start-tp3.sh` with `NCCL_CHANNELS=8` and `TF_GLM_PREFILL_ROWS=4096` ([`config/local.sh.example`](config/local.sh.example)) |
| Rank 0 memory | startup estimate 71.1 GiB; shared KV pool ~4.6M tokens |
| Decode, sparkDash prose | 75.0 tok/s one request · 133.1 at 4 · **186.0 at 8** (aggregate) |
| Cold prefill, sparkDash | 2,361 / **2,469** / 2,396 / **2,232** tok/s at 16K / 32K / 65K / 131K |
| Long context | needle at 131K tokens found (2,170 tok/s) |
| Vision + tool calling | 7/7 on a real-image / real-tool-call suite |
| Start to serving | ~3 minutes |
| Last verified | 2026-10-03, on the hardware below |

**Against the upstream v1.5 three-Spark defaults on the same three Sparks** (harness below): prefill **+7% / +6%**
at 32K / 128K, one-stream decode **+5-7%**, 4 requests +3%, 8 requests the same. For context only (different
hardware, clocks capped at 2,200 MHz there): against the upstream README / changelog sparkDash figures, prose at
4 / 8 requests +9% / +12%, prefill +18-20%, one request 75.0 vs 77.6; our two-Spark runs already measured 7-8%
above those tables before any tuning. Upstream's code figures use a different prompt and are not compared.

## What this adds to the upstream recipe

- **A fabric check that catches what nothing else does.** Re-cabling a GB10 so that both QSFP cages are
  empty at once leaves its ConnectX-7 at ~1/8 RDMA bandwidth until reboot, with every link, PCIe and MTU
  check still green. It cost us 45% of prefill before we found it. [`fabric/check-fabric.sh`](fabric/check-fabric.sh)
  reads the marker and runs a loopback bandwidth test per device. Details: [`../../notes/gb10-cx7-hotplug-ltr.md`](../../notes/gb10-cx7-hotplug-ltr.md).
- **Triangle addressing that survives a peer's reboot** ([`fabric/triangle-addr.sh`](fabric/triangle-addr.sh)).
- **Three settings that help at three ranks**, each beyond the measured start-to-start noise (below).
- **A measured map of what does not help**, so you do not spend restarts on it.
- **A per-rank prefill profile** and two optional engine patches ([`engine/`](engine/)).
- **The harness** ([`bench/tfbench2.py`](bench/tfbench2.py)), the noise-aware comparison
  ([`bench/analyze.py`](bench/analyze.py)) and **all 34 v1.5 runs** ([`bench/results-v15-2026-10-03.jsonl`](bench/results-v15-2026-10-03.jsonl));
  the earlier v1.4 runs with the first harness are in `bench/results-2026-10-03.jsonl` / `bench/tfbench.py`.

## ---------- AGENT.md ATTENTION ----------

If you are an AI agent setting this up on new hardware, in order, confirming each with the operator:

1. **Run `fabric/check-fabric.sh` on every node before the first benchmark**, and again after any
   re-cable or reboot. A node reporting `LTR OFF` or a loopback under ~50 Gb/s gives you wrong numbers
   for everything; reboot it. Do not tune on top of an unchecked fabric - we did once, and threw the results away.
2. **Cable a directed triangle**: each node's port 0 to the next node's port 1. Confirm with LLDP or link
   state, not by trusting labels.
3. **Address each PCIe twin on its own /24 per cable**, both ends; both twins carry traffic only when both
   are addressed. Keep NetworkManager off those ports while you run (see `triangle-addr.sh`).
4. **Check the rendezvous**: `getent hosts $(hostname)` on the head. A loopback answer means you must set
   `MASTER_ADDR` to an address every worker reaches.
5. **Give `COMM` on the command line** (`COMM=roce ./start-tp3.sh`); `start-tp3.sh` ignores it in
   `scripts/local.sh`. **`export`** `TF_GLM_*` settings in `local.sh`, or they never reach the ranks.
6. **Measure noise before you tune.** Three fresh starts of one configuration gave spreads of 0.5% (long
   prefill), ~1% (one-stream decode) and 3-4% (multi-stream aggregates) here. Anything inside that is not a finding.

## Hardware and prerequisites

- Three GB10 systems with 128 GB unified memory, nothing else large on their GPUs (each needs ~110 GiB
  free at start).
- Three QSFP cables, one per pair. Each port appears as two PCIe "twins" (`enp1s0f0np0` / `enP2p1s0f0np0`,
  RoCE `rocep1s0f0` / `roceP2p1s0f0`); one twin is one PCIe Gen5 x4, ~112 Gb/s of the port's 200.
- `arp_ignore=1`, `arp_announce=2` on the fabric netdevs (two twins share one L2 segment).
- The upstream recipe's own prerequisites: Docker with the NVIDIA runtime, key-based ssh from the head to
  each worker's link address, `rsync`, perftest.
- Disk on the head: ~205 GB (checkpoint, DFlash2, image). Workers need only the image (~25 GB) with
  `WORKER_WEIGHTS=nfs`.

## Set up

```bash
# head
git clone https://github.com/MiaAI-Lab/GLM-5.3-Flash-EXL3-2x-DGX-Sparks-TensorFold && cd GLM-5.3-Flash-EXL3-2x-DGX-Sparks-TensorFold
git checkout 1576746          # v1.5, what was measured
cp <this dir>/config/local.sh.example scripts/local.sh   # then fill in
```

1. **Fabric** - on each node, `fabric/triangle-addr.sh <four CIDRs>` (examples in its header), then
   `fabric/check-fabric.sh`. Ping every twin pair from both ends.
2. **NFS** - export the head's HF cache read-only to every worker link address (both twins of both
   cables), e.g. `/home/<you>/.cache/huggingface <w1-a>(ro,no_subtree_check,all_squash,anonuid=1000,anongid=1000) ...`.
3. **ssh** - the head must reach each worker *at its link address* with your key.
4. **Prepare** - `TP=3 scripts/prepare.sh` downloads on the head, copies the image to each worker and checks
   the workers' NFS view file by file. (If you would rather the workers did not pull the image from GHCR
   themselves, kill their `docker pull` and prepare falls back to streaming it from the head over the link.)

### Finding your own values

| Value | How to find it | Why not to copy ours |
|---|---|---|
| Link CIDRs | One /24 per twin per cable, yours | Ours only need to be unique on your fabric |
| `WORKER`, `WORKER2` | The worker's address on the cable to the head | They must route over the cable, not the LAN |
| `MASTER_ADDR` | An address of the head every worker reaches; only needed when the hostname resolves to loopback | LAN layouts differ |
| Which port is "port 0" | `ip -br link` + LLDP; our TOP / BOTTOM cable labels meant port 0 on two units and port 1 on the other two | Mounting orientation flips it |

## Run

```bash
COMM=roce ./start-tp3.sh            # NCCL_CHANNELS and TF_GLM_PREFILL_ROWS come from scripts/local.sh
./stop.sh                           # stops all three ranks
```

Expect, in rank 0's log: `rank 0 of 3`; `all-gathers up to 1024 KiB over RoCE (rank 1 over <two devices>;
rank 2 over <the other two> ...)`; `prompt chunks' hyper-connections: rows split between the ranks ...`;
`--parallel 8`; then `serving ... rank 0 of 3`.

## What moves speed at three ranks (measured)

Method: [`bench/tfbench2.py`](bench/tfbench2.py) from a fourth machine over the LAN, warm-up first, then cold
random-word prefills of ~8K / ~32K / ~128K tokens, one-stream decode of a prose prompt, a copy-friendly code
prompt (fifty near-identical functions) and a natural code task, and prose and natural code at 4 and 8
requests at once. One variable per fresh start; every value read back from the running container. Base: v1.5
with `COMM=roce` and 8 channels, three starts (spread: prefill 32K / 128K 0.6% / 0.5%, prose x1 0.9%, the
4- and 8-stream aggregates 2.5-4.3%). `*` = beyond that metric's noise. Random words prefill 4-8% slower than
sparkDash's filler on this model.

**Helps:**

| setting | prefill 8K / 32K / 128K | one-stream decode | 4 / 8 streams | starts |
|---|---|---|---|---:|
| `TF_GLM_PREFILL_ROWS=4096` (default 2048) | +3.7% / **+6.2%*** / **+5.0%*** | same | same | 3 |
| `COMM=roce` (TP3 default `nccl`) | same (32K / 128K) | **prose +7.3%*, code +5-7%*** | +4% / +2% | 3 v 1 |
| `NCCL_CHANNELS=8` (default 4) | **+10% / +2.6% / +1.9%** (vs 4) | same | same | 3 v 1 |
| v1.5 itself (vs v1.4) | same | same | same / **prose +40%, code +35%** | 3 v 1 |

**Defaults that are right at three ranks:** split prefill (`SPLIT=0`: prefill -25%, measured on v1.4), the `p2p`
split exchange (`gather`: -20%, v1.4), 2 overlap pieces (1: -6%, 4: -3%), L2 prefetch on (off: one-stream decode -2%), draft
policy `fnc7:0.3` (0.2: same or slightly worse).

**No measurable effect** (each within noise): `TF_ROCE_MAX_KB` 512 / 2048 (auto 1024 at 8 streams),
`TF_GLM_MULTI_WINDOW=48` (auto 64), `NCCL_CHANNELS=16`, `NCCL_NCHANNELS_PER_NET_PEER=4`,
`NCCL_P2P_NET_CHUNKSIZE=524288`, `NCCL_BUFFSIZE=8388608`, `vm.compaction_proactiveness=0` (round-gap p99 unchanged
with smoothing off), `TF_GLM_OVERLAP_PRIORITY=-1` (prefill +1.5% at 32K, decode -1.4 to -2.2% at 4 / 8 streams:
not worth it), prompt chunks past 4096 (6144: below 4096 at 32K; 8192: +1-1.5% more for 3 GiB more; 4224's
zero pad rows buy nothing).

**Trade to know about:** 8 requests at once (v1.5's three-Spark default) is throughput, not latency - each
request runs at ~22 tok/s with 8 in flight against ~33 with 4. One request alone is unaffected.

## Where the time goes (per-rank profile)

One 128K-token prompt, `TF_GLM_PROFILE=1` with [`engine/0072-glm-profile-parallel.patch`](engine/0072-glm-profile-parallel.patch)
(the profiler reports nothing under `--parallel` without it), 75.8 s timed on every rank (the profiler's syncs
slow prefill ~22%; the fractions are what to read):

| block | rank 0 | rank 1 | rank 2 |
|---|---:|---:|---:|
| MoE total | 35.0 s | 35.1 | 34.9 |
| routed experts (EXL3) | **18.7** | 16.1 | 16.1 |
| DSA attention total (token selection 7.9, sparse attention 5.6) | 17.6 | 17.6 | 17.6 |
| KDA linear attention | 11.9 | 11.9 | 11.8 |
| hyper-connection glue and its exchanges | 10.7 | 10.6 | 10.9 |

MoE 46%, attention 23%, KDA 16%, glue 14%. **Rank 0 is the routed-expert straggler**: the experts' 2,048
intermediate columns split in 128-column units, 6 / 5 / 5 over three ranks, so the 6-unit rank takes 16% longer
and the others wait ~2.6 s of every 128K prompt (~3.4%). Exchanges hide behind the overlap - which is why no
NCCL setting moved anything.

## Optional engine patches ([`engine/`](engine/))

Both apply on top of the upstream recipe's patch set (v1.5, 0001-0070) and change nothing unless enabled.

- **`0072-glm-profile-parallel.patch`** - `TF_GLM_PROFILE=1` under `--parallel` > 1: arms the prefill profiler
  around the multi-stream engine's whole-chunk fills and reports once per prompt on every rank, which is what
  produced the table above.
- **`0073-tp-remainder-placement.patch`** - `TENSORFOLD_TP_REMAINDER=last` gives a split's remainder units to the
  highest rank instead of rank 0 (MoE 640 / 640 / 768, heads 21 / 21 / 22). The straggler moves to rank 2 and
  prefill is unchanged (the 6-unit rank still sets the pace); one-stream decode ~2% lower and 4 streams ~3% higher
  in both starts (each at its noise line) - but **rank 0, the API host, holds 9.1 GiB less**, and the shared KV pool (the minimum spare across ranks) grew 0.4-0.7M tokens here.

To try one without rebuilding the image, bind-mount the patched file into every rank's container at the
package path (`/usr/local/lib/python3.12/dist-packages/tensorfold/...`) - the upstream `start.sh` has no hook
for extra `docker run` arguments, so that means a local edit of its `RUN_ARGS`.

**Not attempted, measured case for it:** balance the routed experts exactly by splitting the sixteenth
128-column unit by expert instead of by column (every rank keeps 5 units of every expert plus the 16th unit of
96 of the 288 experts). Worth ~2.7% of prefill at 128K from the profile above, likely some decode; it needs
ragged per-expert widths in the EXL3 MoE kernels.

## Pitfalls we hit

- **The hotplug bandwidth trap** - above and in [the note](../../notes/gb10-cx7-hotplug-ltr.md).
- **NetworkManager undoing runtime addresses** on a peer's reboot, and re-adding a `169.254` address that
  NCCL's two-node bootstrap then dials (`NCCL error 2: unhandled system error`).
- **`TF_GLM_*` set in `local.sh` without `export` never reach the ranks**; read the running container's env.
- **When a worker dies during start**, `start.sh` reports it but leaves rank 0's container running;
  `./stop.sh` clears it.

## Security posture

The API binds `0.0.0.0:8888` by default (upstream `HOST`). Keep it on a private network or VPN, or set
`HOST` to a private address. NFS exports go to link addresses only, read-only, squashed.

## Trust notes

- The engine image is the upstream recipe's prebuilt GHCR image, pinned by digest
  (`sha256:ef83797d...` for `v0.6.0-9f73cca659a1`).
- **DFlash2 (`incoai/GLM-5.3-Flash-DFlash2`) is CC BY-NC-ND 4.0, non-commercial.** For commercial use set
  `DRAFTER=mtp` before the first start (one request at a time on v1.5).
- Read the checkpoint's model card for its license and attribution terms before you serve it.

## Credits

[MiaAI-Lab](https://github.com/MiaAI-Lab/GLM-5.3-Flash-EXL3-2x-DGX-Sparks-TensorFold) (Apache-2.0) for the
recipe, the checkpoint and the three-Spark engine; [ashhart/TensorFold](https://github.com/ashhart/TensorFold)
for the engine; incoai for DFlash2; b12x for the RoCEnante transport the recipe uses for small all-gathers.
Bugs in *this* directory are ours.

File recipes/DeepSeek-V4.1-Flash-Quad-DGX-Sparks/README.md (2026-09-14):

# DeepSeek-V4.1-Flash · four DGX Sparks, no switch

Serves [`deepseek-ai/DeepSeek-V4.1-Flash`](https://huggingface.co/deepseek-ai/DeepSeek-V4.1-Flash)
(552B-backbone MoE, 769B with the Engram tables, 16B active, MXFP4 experts,
1M native context) as **one** OpenAI-compatible vLLM endpoint, tensor-parallel
across **four** DGX Spark / ASUS Ascent GX10 units wired as a **switchless
ring** — each unit's two QSFP ports cabled to its two neighbours, no switch
bought, no switch needed.

| | |
|---|---|
| Shape | TP4 across 4 × GB10, rank 0 serves the API |
| Checkpoint | 475 GiB, one copy on the head, read by the others over NFS |
| Per-rank weights | 81.58 GiB resident |
| Context | 300,000 (boot 2/4), **524,288** (boot 6, serving) or 1,048,576 (boot 5) |
| Speculative decoding | DSpark k=5, measured acceptance 3.55 over a 20-minute mixed soak |
| Vision + tool calling | both on, 7/7 on a real-image / real-tool-call suite |
| Decode | **62–63 ms/step**, 93 tok/s counting, C1 55–57 per-stream, C6 144–152 aggregate |
| Cold prefill | 1,755 / 2,152 / 1,958 / 1,590 tok/s at 3K / 12K / 47K / 93K tokens (boot 6); 1,485 at 130K, ~1,250 at 300K |
| Long context | needle exact at **298K / 596K / 993K** tokens |
| Transport | [FujitsuPolycom/sparkring](https://github.com/FujitsuPolycom/sparkring) patched NCCL 2.30.7, four-rank switchless cycle |
| Fabric cost | 4.64 ms of a 63 ms decode step; 531.1 GB per ring link over a 20-min soak |
| Last verified | 2026-09-14 on the hardware described below (boot 6) |

It does **not** fit at TP2 in any layout, so this is a four-node workload or
nothing: while it serves, everything else on those four machines is down.

## What this recipe adds

Three other people have published DGX Spark recipes for this checkpoint, and
this one stands on all of them — [tonyd2wild](https://github.com/tonyd2wild/DeepSeek-V4.1-Flash-vLLM-DGX-Spark)
(the patch set and the launcher this one is adapted from, MIT),
[ZackO2o](https://github.com/ZackO2o/DeepSeek-V4.1-Flash-4x-GB10-1M-Full-Recipe)
(the 1M-context work, MIT), and [MiaAI-Lab](https://github.com/MiaAI-Lab/DeepSeek-v4.1-Flash-DGX-Sparks).
What is here and not there:

- **A switchless four-node ring**, rather than a switch. The transport, the
  routing, the failure modes and the measured cost of the topology are in
  [`../../notes/ring-ops.md`](../../notes/ring-ops.md).
- **Boot profiles as files**, not flags in your shell history: a gate profile,
  a 300K serving profile, a fair-prefill profile, a 1M profile, and the
  current 500K profile with the Engram fast path. Changing the serving shape
  is `cp profiles/<x>.env ~/boot.env && ring-cluster.sh start`, and a
  rollback is the same command with the old file.
- **Fairness under mixed load.** `--long-prefill-token-threshold` measured from
  both sides: what it buys a co-scheduled stream, and what it costs the long
  request.
- **Verification that would catch a silent failure**, not just a clean boot:
  RDMA counters, per-category decode, needle retrieval, a soak, and the
  specific things on this stack that fail *quietly* (a wrong CUDA-graph
  capture list, a patch set built against the wrong commit).

## ---------- AGENT.md ATTENTION ----------

If you are an AI agent deploying this on new hardware, work through these in
order and confirm each with the operator before moving on.

1. **Pin the vLLM commit, and verify what you actually built.** The patch set
   is seven *whole-file* replacements. Against a different tree they still
   load, the engine still boots, and every generation is garbage — that is
   [tonyd2wild#2](https://github.com/tonyd2wild/DeepSeek-V4.1-Flash-vLLM-DGX-Spark/issues/2),
   caused by the branch being force-pushed under a recipe that named a branch
   rather than a commit. Build against
   `e47aa780bccf59f59dfa2cbb18e17a10b4fe69ba` and fetch it **by sha**. Then
   check what you actually built, before any config: `sha256sum` the unpatched
   `vllm/v1/attention/backends/mla/indexer.py` inside the image. `392d93da110e…`
   is the right tree; `416677cea31c…` is the commit after it, and no launcher
   flag will save you there (verified on our own image; the table is in
   [tonyd2wild#2](https://github.com/tonyd2wild/DeepSeek-V4.1-Flash-vLLM-DGX-Spark/issues/2)).
2. **Cable the ring, then prove the cabling.** Do not trust the labels on the
   cables. `lldpctl` (or `ip -d link` plus the switch-less neighbour's MAC) on
   every node, and write the cycle down before configuring anything.
3. **Derive every node's RoCEv2 GID index on that node.** Identical hardware
   enumerates it differently. The launcher refuses a wrong one — that check
   exists because copying a neighbour's value is the obvious mistake.
4. **Never `--host 0.0.0.0`.** `ring.conf` takes a private/VPN address for the
   API. Ask the operator before widening it; the endpoint has no auth.
5. **First boot is `profiles/boot1-eager.env`.** Eager, text-only, 131K,
   no speculation. If it serves and answers coherently, the ring, the
   checkpoint, the patch set and RDMA are all good, and everything after that
   is tuning. Do not start at the serving profile.
6. **Verify with `verify/` and the gate lines, not with "the container is up".**
   A boot that garbles, a boot whose NCCL fell back to TCP, and a healthy boot
   all look identical in `docker ps`.
7. **Do not raise `--max-num-seqs` or hand-write `cudagraph_capture_sizes`.**
   The launcher derives the capture list from `SEQS` and `SPEC_K`; a list that
   never matches a real batch shape produces silent NaN on this stack, not an
   error (see `notes/ring-ops.md`).

## Hardware and prerequisites

- **Four** DGX Spark / ASUS Ascent GX10 (GB10, 128 GB unified memory each).
- Four QSFP cables, wired as a cycle: `0↔1`, `1↔2`, `2↔3`, `3↔0`. Each node
  uses both of its ports, one per neighbour. No switch.
- One /24 per link, and routes so any node can reach any other (two of the
  nodes forward; see `notes/ring-ops.md`). A VPN/tailnet address per node as
  the always-up control plane is strongly recommended — it lets you boot the
  cluster before the fabric routes exist, and to fix them if they break.
- ~500 GB free on the head for the checkpoint, exported read-only to the
  other three (NFS here), plus ~50 GB per worker for node-local Engram rows.
- Docker with GPU support, and `sudo -n` for `drop_caches` and the share mount.
- Patience: a first build is ~2 h, a cold boot is 11–13 min.

## Build

The image is not published anywhere — build it yourself. Follow
[tonyd2wild's build](https://github.com/tonyd2wild/DeepSeek-V4.1-Flash-vLLM-DGX-Spark)
(`build/`), which layers, on `vllm/vllm-openai:nightly`:

1. vLLM `dsv41-feat` **at `e47aa780bccf59f59dfa2cbb18e17a10b4fe69ba`**, fetched
   by sha (`git fetch origin <sha>`), not by branch name.
2. `_C_stable_libtorch` compiled for `sm_121a`.
3. FlashInfer `v0.7.0rc1`, plus the prebuilt `mxfp8_gemm_cutlass_sm120` and
   `sparse_mla_sm120` kernels so the first request does not JIT them.

Build on **one** node and copy the image to the others
(`docker save | ssh | docker load` over the fabric is fastest). Do not build
on a node that is serving: the build wants all the RAM, and vLLM runs with
`--oom-score-adj 500`.

The seven patch files come from tonyd2wild's `patch/` directory with its
`mounts.txt`; md5-verify them against that repo's `patch/README.md` after
copying to `$PATCH_ROOT/<name>/` on all four nodes.

## Configure

```bash
cp launch/ring.conf.example launch/ring.conf   # then fill in, per the comments
```

Every value in `ring.conf` is read off your own machines. The examples are
placeholders and will not work anywhere.

### Finding your own values

| Value | How to find it | Why not to copy it |
|---|---|---|
| `RANKn_HOST` | `hostname` on each node | The launcher refuses a rank on the wrong machine; that only works if these are right |
| `RANKn_HCA` | `ibv_devices`, then match to the ports you cabled | Port naming differs between machines of the same model |
| `RANKn_GID` | For each HCA: the index `i` where `/sys/class/infiniband/<hca>/ports/1/gids/<i>` is `::ffff:<your fabric IPv4>` **and** `gid_attrs/types/<i>` says `RoCE v2` | Differs per node. Ours were 3 on two nodes and 5 on the other two, same model, same day |
| `RANKn_FAB_IP/IF` | Your own addressing, one /24 per link | — |
| `RANKn_PRIV_IP`, `PRIV_IF` | Your VPN/tailnet address and interface | — |
| `NCCL_SO_SHA256` | `sha256sum` of the patched NCCL you downloaded | The launcher verifies the transport binary on every boot; an empty value only warns |

## Run

Workers first, head last, every time.

```bash
# on each node, or from one node with launch/ring-cluster.sh
. profiles/boot1-eager.env
IMAGE=<your image> bash launch/ring-launch.sh 3   # then 2, then 1, then 0
```

or, from any node that has SSH to the others:

```bash
cp profiles/boot2-serving-300k.env ~/boot.env
R0=user@rank0 R2=user@rank2 R3=user@rank3 bash launch/ring-cluster.sh start
bash launch/ring-cluster.sh gates
```

Stopping is `ring-cluster.sh stop` (head first — a worker that joins a
still-listening old head hangs the next boot). Never `pkill -f 'vllm serve'`:
vLLM renames its `EngineCore`/`Worker_TP*` children, so that pattern kills the
launcher and orphans the workers, which keep the GPU and the port.

### Gate lines to expect

```
Model loading took 81.58 GiB memory and ~295 seconds
Engram DISK mode: layer N rows [a, b) read from model-000NN-of-00048.safetensors
Graph capturing finished in 6 secs, took 1.78 GiB
GPU KV cache size: 1,992,707 tokens, Maximum concurrency for 1,048,576 tokens per request: 1.90x
Application startup complete.
```

`Model loading took 81.58 GiB` is the strongest single signal that you built
and patched the right thing: three independent fleets report the same number
to two decimals. A different number means a different tree.

## Measured

All on four GB10 units on the switchless ring, temperature 0, thinking off,
prompt set held constant across boots.

### Decode (boot 2 / boot 4, 300K window)

| concurrency | aggregate tok/s | per-stream tok/s | mean TTFT (s) |
|---|---:|---:|---:|
| C1 | 50.4 | 57.2 | 0.30 |
| C2 | 77.4 | 44.5 | 0.35 |
| C3 | 96.1 | 36.7 | 0.38 |
| C4 | 117.9 | 34.7 | 0.40 |
| C6 | 151.9 | 29.0 | 0.48 |

Per-stream C1 by category — the spread matters more than the headline, because
the mean of eight categories is not comparable to anyone's single prompt:

| counting | tables | code | math | reasoning | JSON | summary | prose | narrative |
|---:|---:|---:|---:|---:|---:|---:|---:|---:|
| 90.5 | 90.0 | 75.6 | 69.1 | 63.0 | 59.7 | 36.8 | 33.1 | 30.6 |

That is a 3× spread on one engine in one run, and it tracks DSpark acceptance
(counting and code accept near the k+1 maximum of 6; prose and narrative near
2). At a 63 ms step, 2.0 accepted tokens/step is 31.7 tok/s and 5.85 is 92.9 —
so a "slow" number on a prose prompt is not a broken fleet.

### Long context (boot 5, 1M window, gmu 0.83)

| prompt tokens | TTFT (s) | prefill tok/s | needle |
|---:|---:|---:|---|
| 298,172 | 222.6 | 1,340 | exact |
| 596,196 | 522.4 | 1,141 | exact |
| 993,435 | 1,032.7 | 962 | exact |

KV pool at 1M: **1,992,707 tokens = 1.90×** a full-window request. Decode is
unchanged from the 300K profile (62.4–63.6 ms/step, C1 55.2, C6 143.8), so on
this hardware the 1M window costs pool headroom, not speed. Note prefill rate
falls with length — a full 1M prompt is a 17-minute first token, and your
client's timeout, not the model, is what will break first.

### Soak (8 streams, 20 minutes, mixed categories)

829 requests, **0 errors, 0 hangs, 0 preemptions**, 104.7 tok/s aggregate,
TTFT p50 0.79 s, longest gap between two chunks of any stream 0.72 s, DSpark
acceptance 3.55. Every ring link moved 531.1 GB in that window, all four within
0.1 GB of each other.

### The long-prefill threshold, both directions

During a cold 210,041-token prefill (TTFT 114 s), a short stream started 15 s
in got its first token in 2.4 s and then a chunk **every 1.03 s** at
`--long-prefill-token-threshold 2048`. Without the cap that gap is one full
8192-token prefill step. The cost is on the long request: cold prefill drops
9–13% above the cap (1,544 tok/s at 40K vs 1,720 uncapped; 1,488 at 130K vs
1,635), and nothing below it — prompts under the threshold, and prefix-cached
turns that add fewer new tokens than the threshold, are unaffected. `4096`
halves both the benefit and the cost; `8192` is a no-op.

### Boot 6: Engram fast staging, 128 read threads, 500K window

tonyd2wild ran a 40-boot speed run on 2026-09-14 (one change per boot, on
their EXL3 3.5-bpw lane). Two of its levers are Engram-path changes and so
lane-independent — the Engram tables are the same on the native checkpoint —
and both transfer:

- `DSV41_ENGRAM_FAST=1`: their `engram.py` is byte-for-byte the boot-10
  `engram.py` plus a 151-line env-gated diff (memmap row gather on the read
  pool, raw fp8 rows + scales to the GPU, dequant there). Verified by applying
  their `engram-fast.diff` to our file and comparing md5s — the same check as
  for any whole-file patch, below.
- `ENGRAM_THREADS=128` (was 32).

Plus `MAXLEN=524288`: 500K is enough here, and the pool goes from 1.9× a 1M
request to **4.9–5.2× a 500K one** (2.55–2.71M tokens across three boots).

| | boot 5 (1M) | boot 6 (500K, fast path) |
|---|---:|---:|
| decode, counting | 62.4–63.6 ms/step | 62.0 ms/step, 93 tok/s |
| C1 / C6 | 55.2 / 143.8 | 54.7 / **152.1** |
| cold prefill 2,950 tok | 1,470–1,538 | **1,755** (+16%) |
| cold prefill 11,592 tok | 1,452 | **2,152** (+48%) |
| cold prefill 46,810 tok | 1,538 | **1,958** (+27%) |
| cold prefill 93,335 tok | 1,520 | 1,590 (+5%) |
| needle 130,258 tok | 1,474–1,488 | 1,485 (same, exact) |
| needle 298,172 tok | 1,340 | 1,235 / 1,256 (−7%, exact, repeated) |
| vision + tools | 7/7 | 7/7 |

The gain falls monotonically with prompt length and goes slightly negative at
300K. `vmstat` during a 300K prefill showed ~0 disk reads and an idle CPU on
head and worker, so it is neither the memmap thrashing nor 128 threads
contending: the fast path moves dequant onto the GPU, which pays where the
CPU gather was the bottleneck and costs a little where the GPU already is
(the sparse indexer's share grows with context). Keep it if your prompts are
mostly under 100K; a `DSV41_ENGRAM_FAST=0` boot, everything else equal, is
the A/B if you need the 300K number back.

From the same speed run, tried or dispositioned on this fleet:

- **`NCCL_MAX_NCHANNELS=8`** — +10.7% C6 on their switched fleet. Here, as its
  own boot against boot 6: C6 154.2 vs 152.1, everything else inside
  run-to-run noise, NCCL's pinned `Shmem` +29% on the head. Neutral on the cycle (which is
  what sparkring's own thread reports); reverted to 4.
- **b12x RoCE one-shot all-reduce** — their biggest decode lever (code +11%,
  prose +16%). It is a one-shot all-to-all RDMA collective on a single HCA;
  a ring cannot do it. This is the first concrete decode number a switch
  would buy on this workload.
- **`expandable_segments:False`** — they keep it at no speed cost; on our
  NCCL path it cost 19–37% decode when A/B'd (their small all-reduces bypass
  NCCL via b12x, plausibly why they don't pay). Rejected here.
- Indexer prefill TP-split (+6% at 131K for them; applies cleanly to the
  boot-10 indexer file) — not tried yet, small.
- The SGLang lane — 2–2.5× slower, their own verdict.

## Verifying a whole-file patch before you mount it

Whole-file patches belong to the tree they were cut from. Mounting an older
file over a newer tree *boots* and is wrong — that is the failure mode behind
the garbling issue, and it is worth 60 seconds to rule out. Before adding
anyone's file (for example ZackO2o's `gpu_worker.py` for the 1M profile):

```bash
# the file as YOUR image has it
docker run --rm --entrypoint cat <your image> \
  /usr/local/lib/python3.12/dist-packages/vllm/v1/worker/gpu_worker.py > ours.py
diff ours.py theirs.py
```

You want to see *only* the changes their README documents. Ours showed exactly
four hunks (an env gate on the graph-memory profiling pass, `warmup_kernels`
moved before capture, the matching removal after it, and a post-capture state
cleanup) and nothing else — so their base was our pinned commit and the file
was safe to mount. Anything else in that diff means re-derive, don't mount.

## Security posture

The API binds to `RANK0_API_IP` from `ring.conf` and has **no authentication**.
Put a private/VPN address there. `0.0.0.0` on a machine with a public interface
publishes an unauthenticated endpoint that can generate arbitrary text and read
whatever you have mounted into the container; that is your decision to make
deliberately, not a default this recipe will make for you.

The container runs `--cap-add IPC_LOCK --device /dev/infiniband` rather than
`--privileged`, which is the narrower grant that still lets NCCL use RDMA.

## Trust notes

- **The checkpoint** is DeepSeek's own (`deepseek-ai/DeepSeek-V4.1-Flash`).
  Pin `model_revision` and verify sizes after download; ours was
  `dba1be0a40aa45a94ad051997016db3960a90277`, 88 files, 510,313,353,565 B.
- **The patch set** (tonyd2wild, MIT) is seven whole-file Python replacements
  that run inside the engine. Read them, or at least md5-verify them against
  the repo's own `patch/README.md`, and pin the vLLM commit they were cut from.
  [im0xMagnus's PR #4](https://github.com/tonyd2wild/DeepSeek-V4.1-Flash-vLLM-DGX-Spark/pull/4)
  regenerates them as repo-relative diffs, which is easier to review — we
  verified those diffs apply at `e47aa780b` and reproduce the seven files
  byte-for-byte.
- **The patched NCCL** (sparkring, Apache-2.0) is a shared object you
  `LD_PRELOAD` into the engine. Pin its sha256 in `ring.conf`; the launcher
  checks it every boot.
- **ZackO2o's `gpu_worker.py`** (MIT), only if you use the 1M profile — verify
  it against your own image first, as above.
- Nothing here is vendor-validated. NVIDIA does not list this checkpoint, this
  topology, or this vLLM tree as supported on DGX Spark.

## Upgrading the engine: read this before you try

vLLM `main` has since gained DSv4.1-specific work worth wanting (fused
per-step metadata preparation, a hardened top-k gather, a `DeepSelect` top-k
path). Rebasing the patch set onto it, as of 2026-09-14, is **not** a rebase:

- The SM12x top-k fix became a flag — `--sparse-indexer-topk-backend per_row`
  — because the dispatch it patched moved into a new module.
- The indexer backend was renamed and moved, so the 64-state page subclass
  needs re-pointing.
- The Engram work is structural: upstream now implements `cpu_offload` as
  pinned host memory over UVA, which on GB10 comes out of the same 128 GB the
  GPU uses. The disk-backed table + node-local rows that make four Sparks work
  at all have to be re-derived as a third storage backend behind upstream's new
  hooks. There are no reference numbers for that on this hardware yet.

We measured that surface and stayed on the pinned commit. If you are reading
this later, check whether upstream has rebased before spending the two hours.

## Credits

[tonyd2wild](https://github.com/tonyd2wild/DeepSeek-V4.1-Flash-vLLM-DGX-Spark)
(MIT) for the patch set, the build and the launcher this one adapts;
[FujitsuPolycom/sparkring](https://github.com/FujitsuPolycom/sparkring)
(Apache-2.0) for the switchless-ring NCCL and the four-rank cycle environment;
[ZackO2o](https://github.com/ZackO2o/DeepSeek-V4.1-Flash-4x-GB10-1M-Full-Recipe)
(MIT) for the 1M-context patch and the gmu→KV-pool curve;
[im0xMagnus](https://github.com/im0xMagnus) for the repo-relative diffs;
[MiaAI-Lab](https://github.com/MiaAI-Lab/DeepSeek-v4.1-Flash-DGX-Sparks) for
the GB10 profiling work. Bugs in *this* recipe are ours.

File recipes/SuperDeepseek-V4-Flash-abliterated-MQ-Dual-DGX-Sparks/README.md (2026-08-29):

# SuperDeepseek-V4-Flash-abliterated-MQ · Dual DGX Spark

Serves [`Jiunsong/SuperDeepseek-V4-Flash-abliterated-MQ-2xDGX`](https://huggingface.co/Jiunsong/SuperDeepseek-V4-Flash-abliterated-MQ-2xDGX)
(304B-class MoE, mixed FP4/FP8/BF16, 1M-token configured context) as one
OpenAI-compatible vLLM endpoint split tensor-parallel across two **NVIDIA DGX
Spark / ASUS Ascent GX10** units joined by their direct QSFP fabric port.

| | |
|---|---|
| Runtime image | `ghcr.io/anemll/dspark-vllm-gx10:0.1.1` |
| vLLM | `v0.25.2.dev0+g752a3a504.d20260714` (checkpoint author's fork) |
| Nodes | 2 × DGX Spark / ASUS Ascent GX10, tensor-parallel |
| Context | 1,048,576 tokens configured |
| Concurrency | `--max-num-seqs 12` (raised from upstream's tested `6` - see below) |
| Measured throughput | up to 171.9 tok/s aggregate (end-to-end, concurrency 12) |

This recipe **adapts** the checkpoint's own `repro/scripts/` launchers to run
on a generic two-node pair instead of the author's specific hosts. Every
deviation from upstream is called out, with the reasoning, in the script
headers and below - read those before changing anything.

## ---------- AGENT.md ATTENTION ----------

If you are an AI agent deploying this recipe on new hardware: do not run
either script as-is. Both have a block of placeholder values at the top of
`serve-superdeepseek-dual.sh` that **must** be replaced with values you
discover on the actual target machines, not copied from this file or
inferred from context. In order:

1. **On each node**, run `hostname -s` and set `expected_hostname_a`
   (head/API node) / `expected_hostname_b` (worker node) to the real
   results. Do not skip this seal - some GB10 units ship with duplicate
   machine-ids, so hostname is a real safety check, not decoration.
2. **On each node**, run `ip -br link` and identify the fabric NIC (the
   interface carrying the direct QSFP link between the two nodes, *not*
   the tailnet/management interface). Set `netdev` and the two fabric IPs
   (`master_addr` for the head node, `worker_fabric_addr` for the worker)
   to what you actually find - `enp1s0f1np1` and `10.10.10.x` here are
   this recipe's example values, not defaults to assume.
3. **On each node**, run `ibv_devices` for the RDMA device name
   (`rdma_device`), then `show_gids` for the GID index (`gid_index`) -
   pick the RoCEv2/IPv4 entry. **Never reuse the index from this or any
   other recipe**; it is driver/hardware-specific and a wrong value
   typically fails closed rather than silently degrading, but confirm
   rather than assume either way.
4. Determine the operator's actual private/VPN address for the head node
   (Tailscale, WireGuard, or private LAN) and set `api_bind_addr` to that.
   **Never** set it to `0.0.0.0` or a public IP - ask the operator which
   private network to bind if it isn't obvious, do not guess or default to
   the broadest option.
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

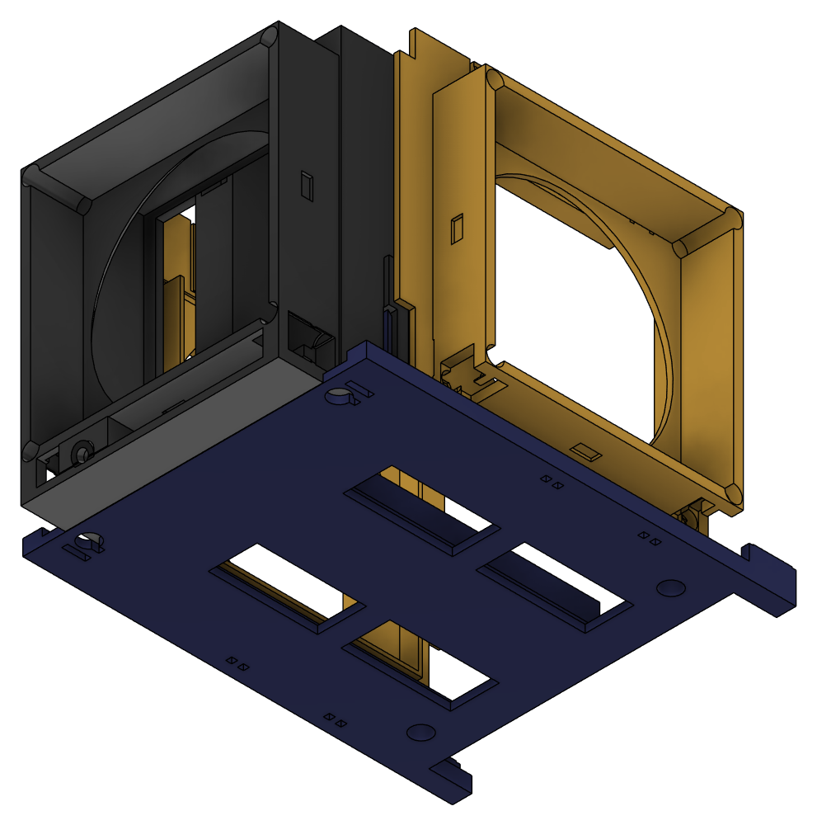
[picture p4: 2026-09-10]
design/cooling-cage/images/cable_rear.png

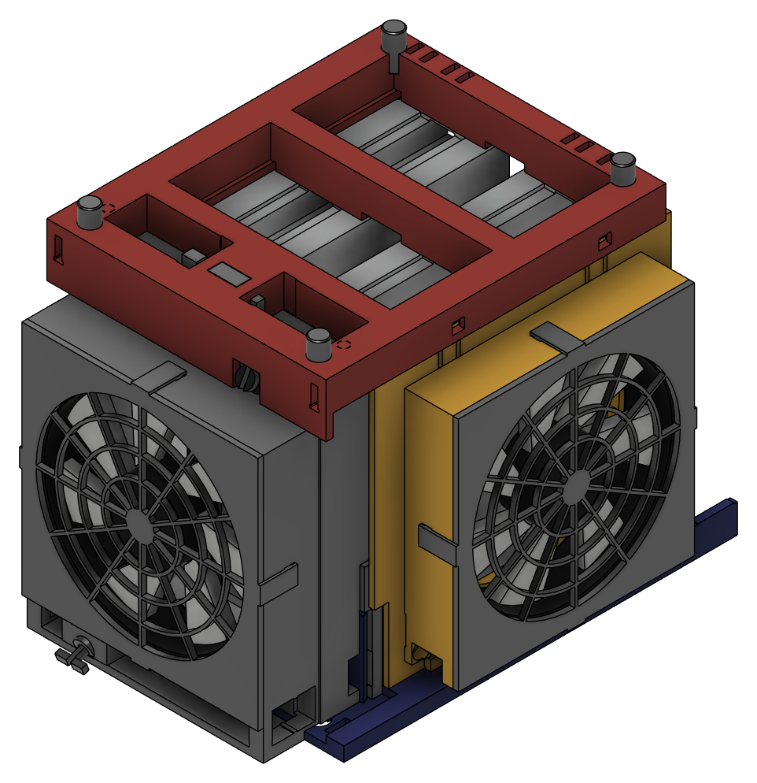
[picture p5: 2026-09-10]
design/cooling-cage/images/s8_done.png

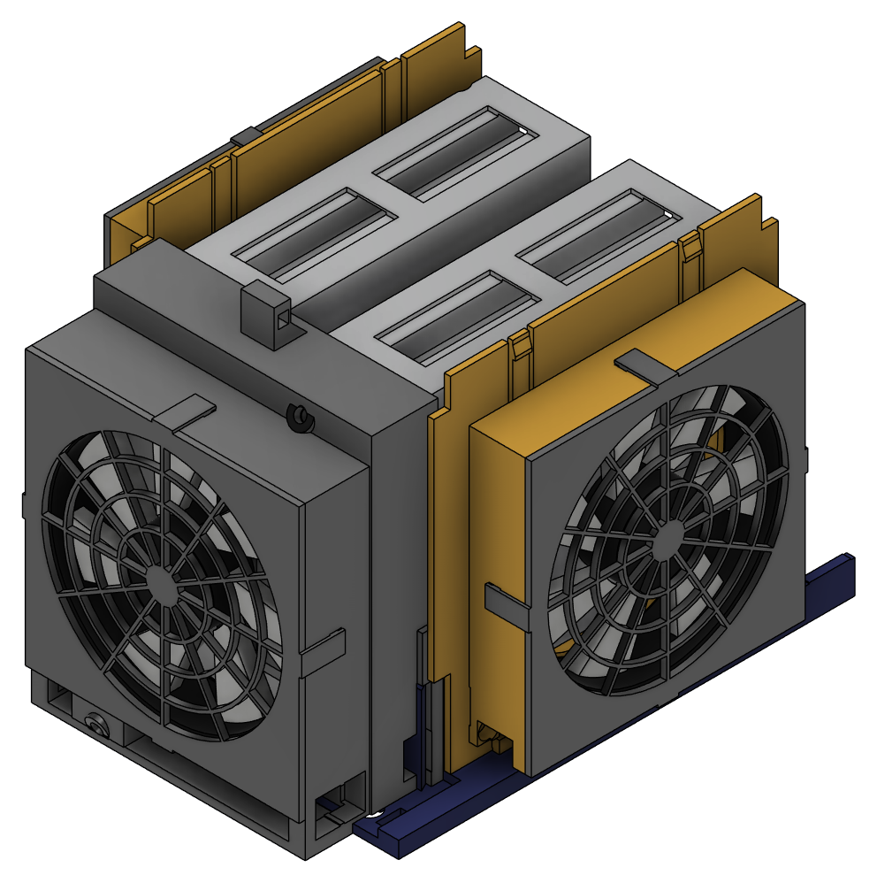
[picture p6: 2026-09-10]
design/cooling-cage/images/s6_grilles.png

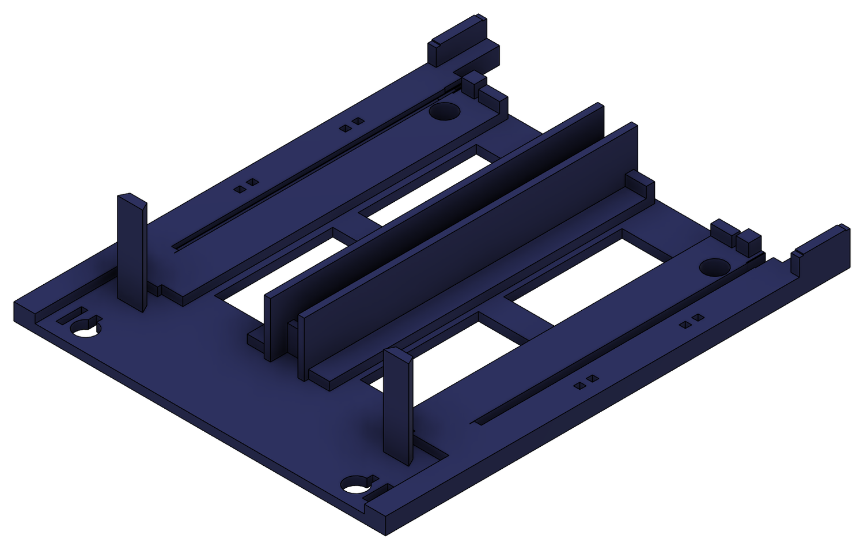
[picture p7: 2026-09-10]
design/cooling-cage/images/s1_tray.png

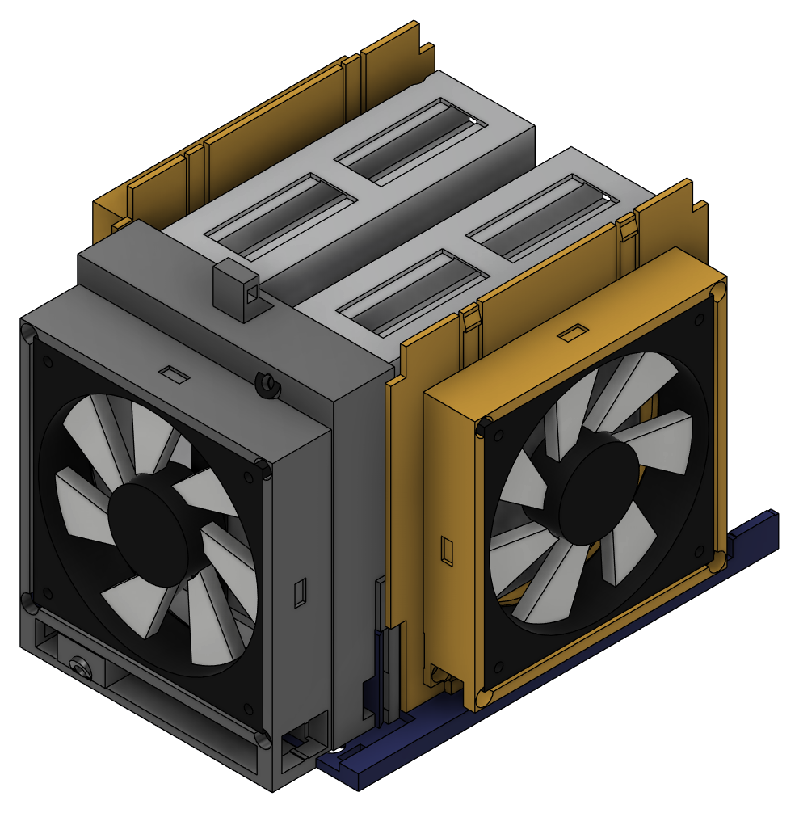
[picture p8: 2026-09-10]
design/cooling-cage/images/s5_fans.png

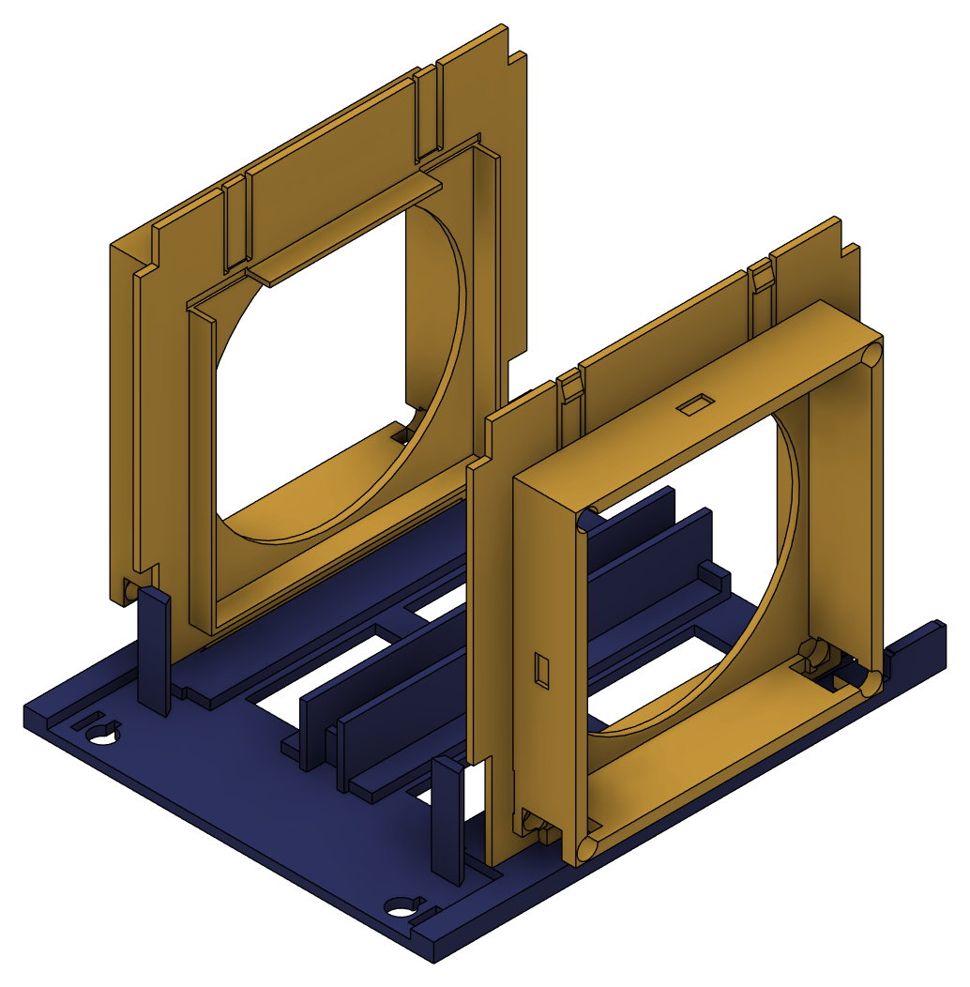
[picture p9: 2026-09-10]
design/cooling-cage/images/s2_arms.png

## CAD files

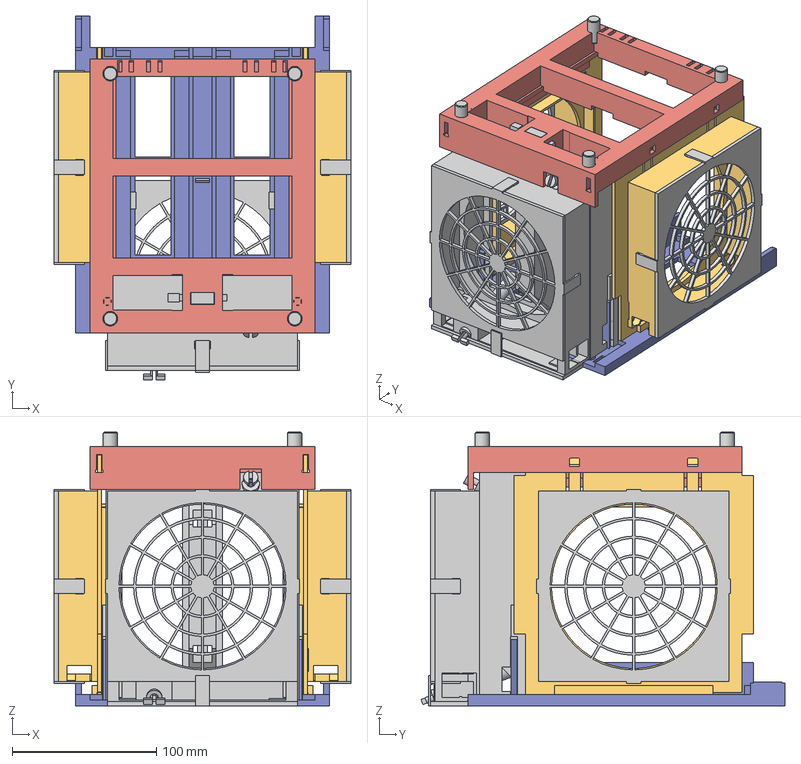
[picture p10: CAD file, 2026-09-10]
design/cooling-cage/cad/dgx-spark-cooling-cage.step
206.0 x 252.6 x 190.0 mm
PRT_04_Top_Brace
PRT_03_Side_Fan_Arm x 2
PRT_01_Base_Tray
PRT_05_Fan_Grille x 3
PRT_02_Front_Plenum
PRT_07_Stack_Peg x 4
PRT_06_Wedge_Key
PRT_08_Button_Pin_Low
PRT_09_Button_Pin_High
PRT_05B_Fan_Grille_25mm

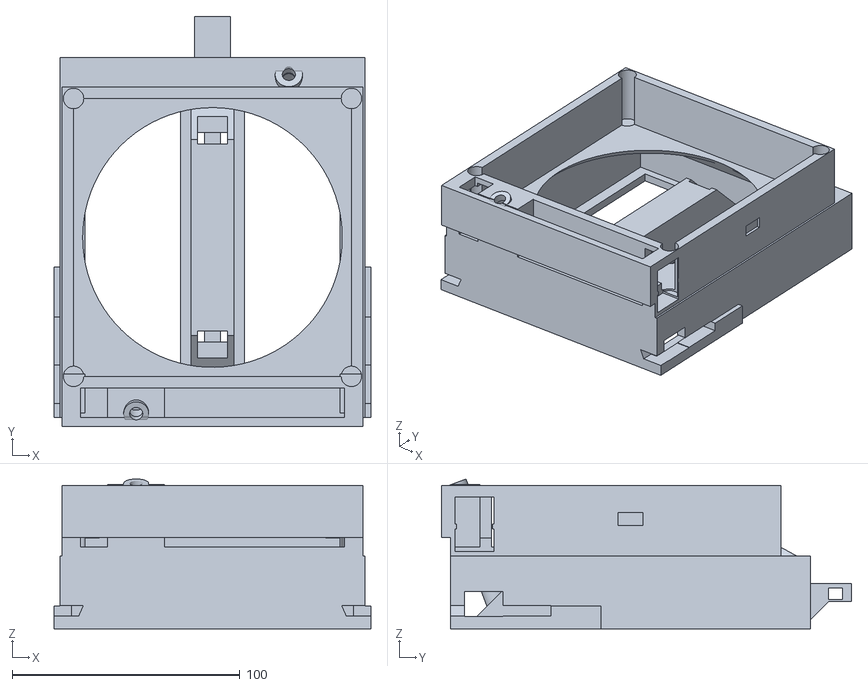
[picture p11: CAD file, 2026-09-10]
design/cooling-cage/print/stl/02-front-plenum.stl
139.0 x 180.0 x 65.9

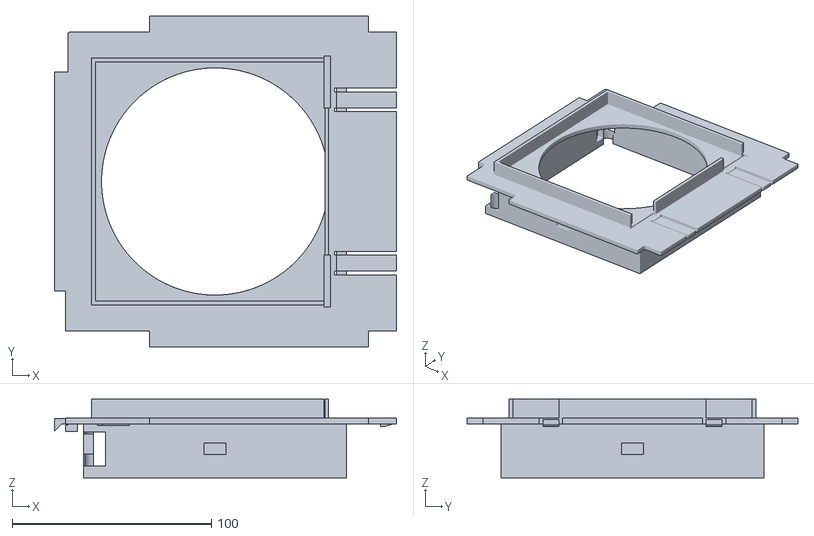
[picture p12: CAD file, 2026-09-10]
design/cooling-cage/print/stl/03-side-fan-arm.stl
171.6 x 166.0 x 39.6

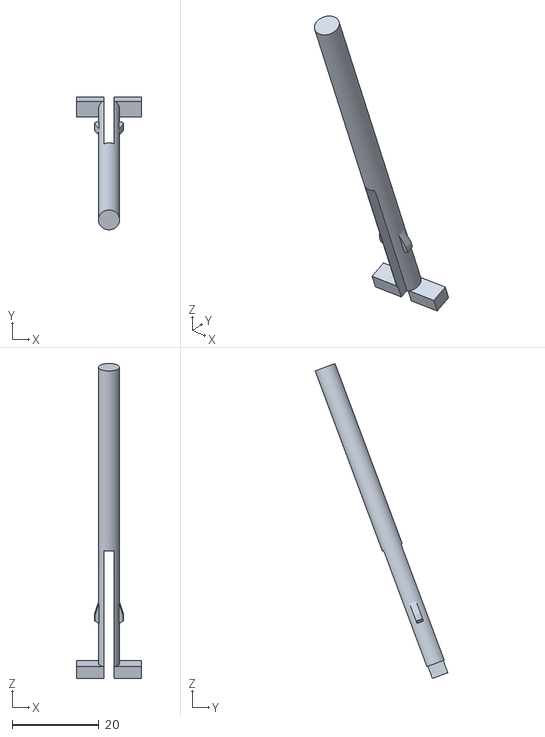
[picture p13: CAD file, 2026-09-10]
design/cooling-cage/print/stl/08-button-pin-long.stl
15.0 x 30.5 x 72.5

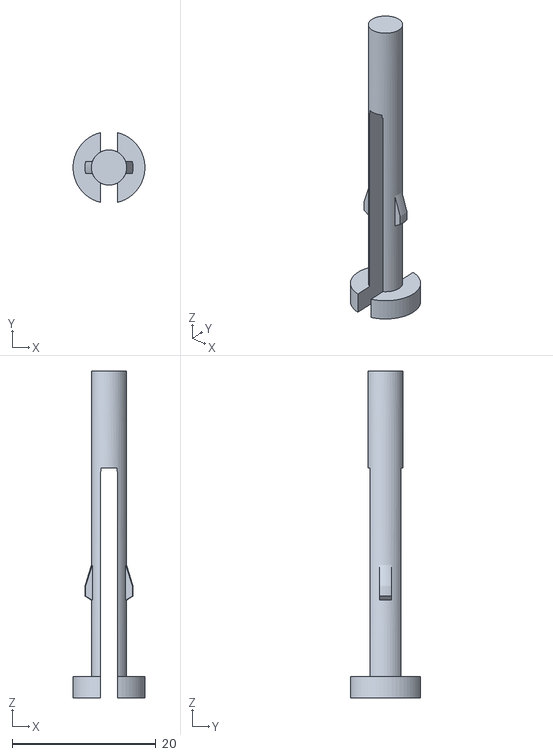
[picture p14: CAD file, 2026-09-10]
design/cooling-cage/print/stl/09-button-pin-short.stl
9.98 x 9.71 x 45.5

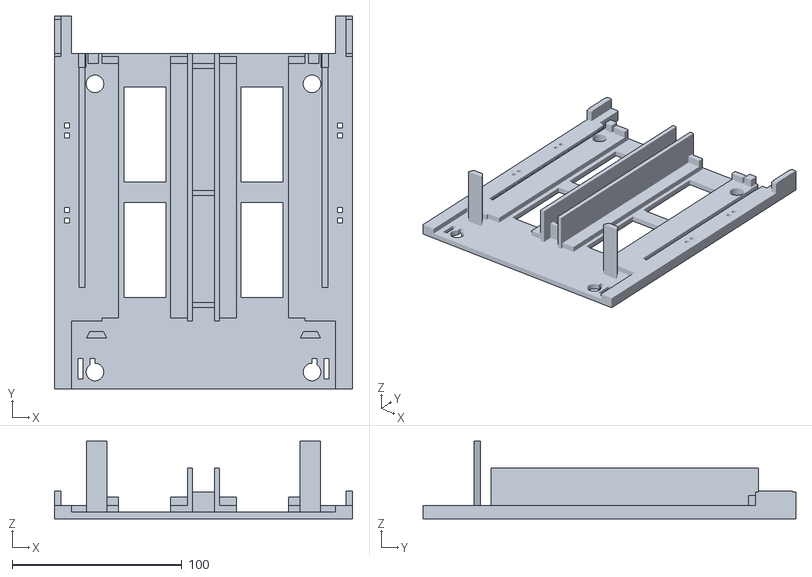
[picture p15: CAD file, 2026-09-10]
design/cooling-cage/print/stl/01-base-tray.stl
176.0 x 220.0 x 46.0

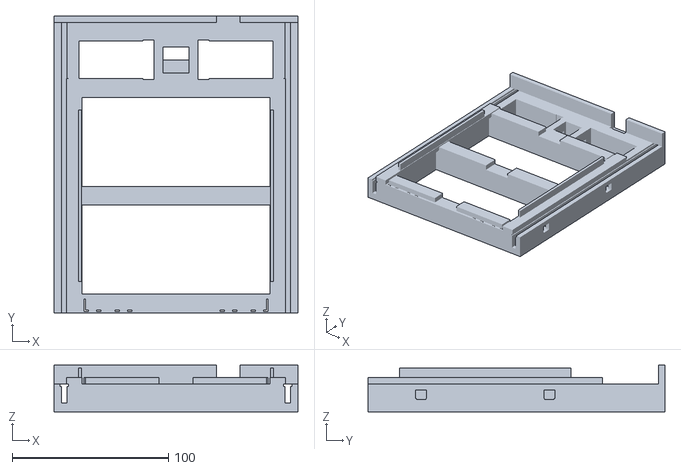
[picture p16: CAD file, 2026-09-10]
design/cooling-cage/print/stl/04-top-brace.stl
156.0 x 190.0 x 30.0

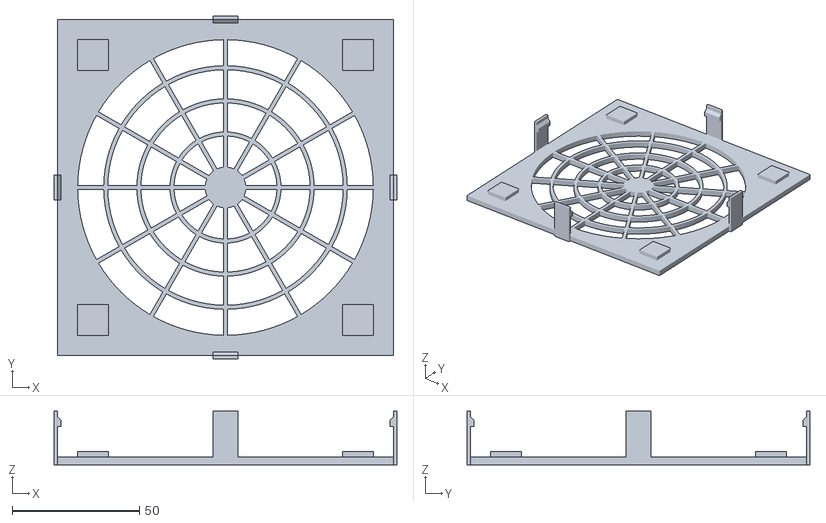
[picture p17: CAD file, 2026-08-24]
design/cooling-cage/print/stl/05b-fan-grille-25mm.stl
134.6 x 134.6 x 21.0

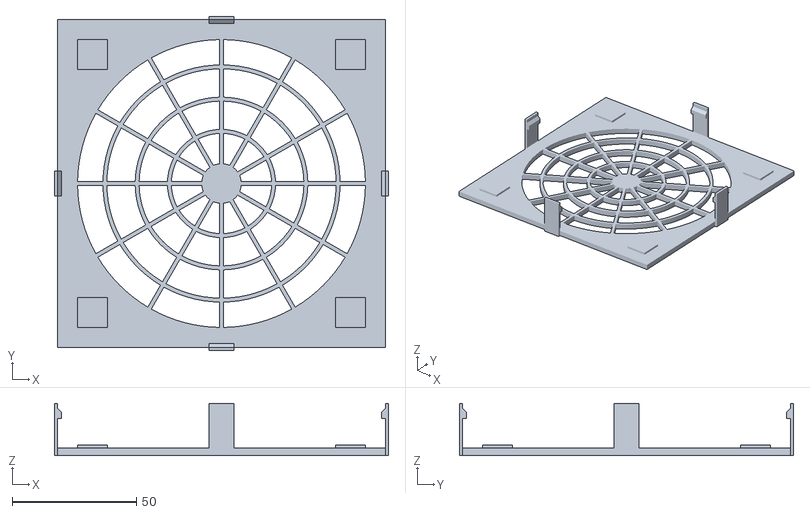
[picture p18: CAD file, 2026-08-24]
design/cooling-cage/print/stl/05-fan-grille-26mm.stl
134.6 x 134.6 x 21.0

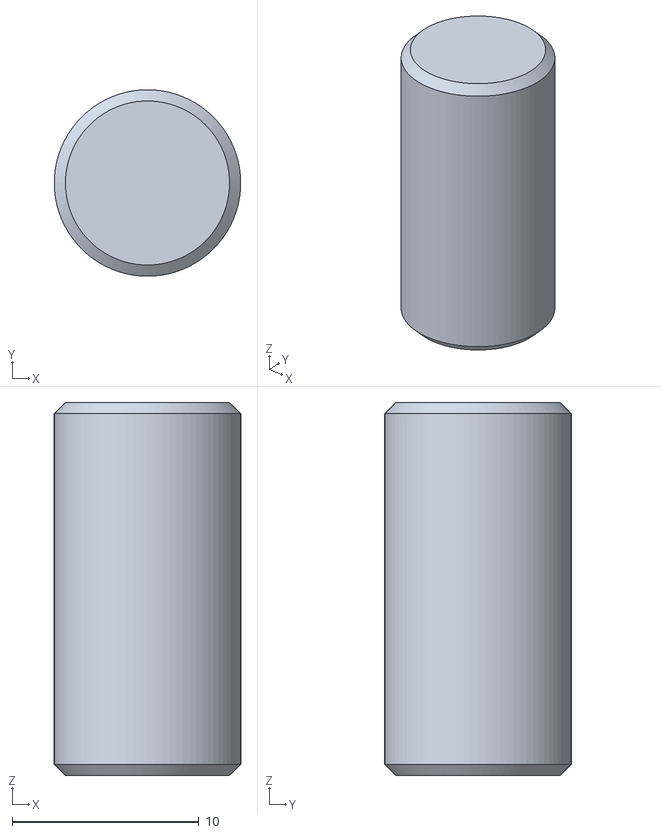
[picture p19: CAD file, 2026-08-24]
design/cooling-cage/print/stl/07-stacking-peg.stl
10.0 x 10.0 x 20.0

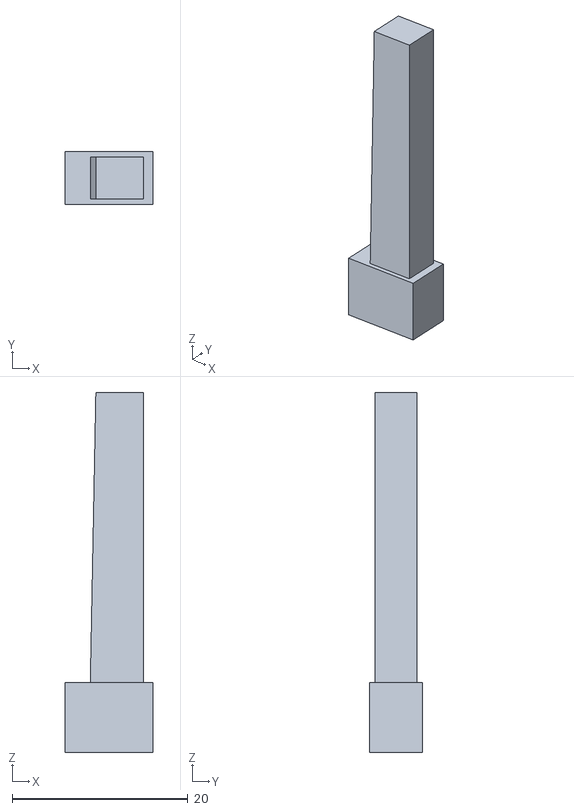
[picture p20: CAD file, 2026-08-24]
design/cooling-cage/print/stl/06-wedge-key.stl
10.0 x 6.00 x 41.0

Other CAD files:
design/cooling-cage/cad/dgx-spark-cooling-cage.f3d
design/cooling-cage/print/dgx-spark-cooling-cage.3mf

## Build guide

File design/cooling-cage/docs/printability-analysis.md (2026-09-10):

# Printability: orientation and support requirements

Model v33. Every figure measured from the exported meshes, not estimated.

> **This document was rewritten on 2026-09-10.** The previous version concluded that no part
> needed support material. That conclusion does not survive re-measurement. Two of its rows were
> wrong, and one of its recommendations made a part worse. What changed and why is at the bottom.

## How this is measured

A bridge proxy — `2 × area / perimeter` on each downward-facing face — cannot tell a **bridge**
(anchored at both ends, prints fine) from a **cantilevered ledge** (anchored on one side, droops).
So the measurement is **unsupported reach** instead.

The part is ray-cast into vertical columns at 1.0 mm spacing and sliced at 0.5 mm. A cell is an
overhang if it has material with nothing directly beneath it and is not on the bed. For each such
cell, a distance transform gives the horizontal distance to the nearest column that *does* carry
material one layer down — the nearest anchor the extruded filament can reach.

```
reach r  =  distance to the nearest anchor
    bridge of span S    ->  midpoint reach = S/2
    cantilever length L ->  tip reach      = L
```

`r < 3 mm` is self-supporting in practice. `r > 10 mm` means either a 20 mm+ bridge or a 10 mm+
cantilever, past the 20 mm span limit this design set for itself.

Validated on a known case: the stacking peg reports ~0 mm² standing on its end, and ~120 mm² at
about 1 mm reach lying on its side, which is right for a plain cylinder.

## Results — all ten parts, as exported

| Part | Build direction | Overhang | r>5 mm | r>10 mm | Worst reach | Support |
|---|---|---|---|---|---|---|
| `01-base-tray` | floor down | 1 112 mm² | 0 | 0 | 1.0 mm | none |
| `02-front-plenum` | back plate down | 11 946 mm² | 2 540 | **997** | **19.0 mm** | **needed** |
| `03-side-fan-arm` | fan collar up | 14 978 mm² | 8 706 | **4 156** | **26.6 mm** | **needed** |
| `04-top-brace` | top face down | 1 494 mm² | 0 | 0 | 5.0 mm | none |
| `05-fan-grille-26mm` | grille face down | 60 mm² | 0 | 0 | 2.0 mm | none |
| `05b-fan-grille-25mm` | grille face down | 60 mm² | 0 | 0 | 2.0 mm | none |
| `06-wedge-key` | on its side | 0 mm² | 0 | 0 | 0.0 mm | none |
| `07-stacking-peg` | on end | 12 mm² | 0 | 0 | 1.0 mm | none |
| `08-button-pin-long` | widest face down | 152 mm² | 0 | 0 | 2.8 mm | none |
| `09-button-pin-short` | oblique | 14 mm² | 0 | 0 | 1.4 mm | none |

**Eight of ten are clean.** The two large parts are not, and no orientation fixes them.

## The arm has no support-free orientation

The arm is a flat plate roughly 166 × 172 mm and 3 mm thick, with the shroud collar standing
9.6 mm off one face and the rails and bosses standing about 27 mm off the other. The plate can
never sit on the bed: something is always underneath it.

What is underneath is not much. Probing the solid — for each point on the plate, is there any
material outboard of it?

```
rows = z 10..170, cols = y 0..150; P = plate with nothing behind it, R = rib behind, . = no plate
z= 10 .PPPPRRRRRRRRRRRRRRRRRRRRRPPPP.
z= 60 PPRPP.....................PPRPP
z= 90 PPRP.......................PRPP
z=120 PPRPPPP.................PPPPRPP
z=150 PPPPPP.P.PPPPPPPPPPPPP.P.PPPPPP
```

Two narrow rails and a band near z = 10-20. That is the entire support available to a 13 000 mm²
plate.

All six axis orientations, measured:

| Build direction | Overhang | r>5 mm | r>10 mm | Worst reach | Footprint × height |
|---|---|---|---|---|---|
| **fan collar up (as exported)** | 14 978 | 8 706 | 4 156 | 26.6 mm | 172 × 166 × 40 |
| fan collar down | 16 473 | 11 531 | 7 832 | 39.2 mm | 172 × 166 × 40 |
| on end, brace end up | 9 756 | 4 815 | 2 494 | 25.5 mm | 40 × 166 × 172 |
| on end, tray end up | 10 132 | 5 883 | 3 618 | 27.1 mm | 40 × 166 × 172 |
| on its side, front up | 10 277 | 6 520 | 3 992 | 42.0 mm | 172 × 40 × 166 |
| on its side, rear up | 10 275 | 6 521 | 3 989 | 41.0 mm | 172 × 40 × 166 |

Standing it on end is the least bad on area but it is a 172 mm tower on a 40 × 166 footprint and
it still needs support. **The files ship it fan-collar-up and it needs support there.** Tree
supports under the plate are enough; the plate itself is flat and 3 mm thick, so it takes support
cleanly and the underside is an internal face nobody sees.

In v1 there was no collar. The plate went straight on the bed, rails up, and the part genuinely
was support-free. **Adding the collar in v2 is what removed that option**, and the v2 analysis
did not catch it.

## The plenum has been re-oriented back

The v2 pass moved the plenum from back-plate-down to upright, on a prediction of 2 mm² beyond
10 mm reach. Measured, upright is far worse:

| Plenum orientation | Overhang | r>5 mm | r>10 mm | Worst reach | Footprint × height |
|---|---|---|---|---|---|
| **back plate down (as exported)** | 11 946 | 2 540 | **997** | **19.0 mm** | 139 × 180 × 66 |
| upright (v2, now reverted) | 17 387 | 9 347 | 6 706 | 40.1 mm | 139 × 66 × 180 |

Back-plate-down is a factor of 6.7 better on area beyond 10 mm reach and halves the worst reach,
and it is a 66 mm tall print instead of 180 mm. It still needs support under the front face.

## What the previous version got wrong

The old analysis is reproducible for **eight of the ten parts**, including its own calibration
case, so the method was right and the implementation was wrong somewhere that only bit the two
large parts. Its arm row reported 189 mm² beyond 5 mm reach where the same orientation measures
8 706; its plenum recommendation predicted 2 mm² beyond 10 mm where the delivered orientation
measures 6 706.

The lesson is the one already in `design-notes.md`, applied to the analysis instead of the model:
a number that says a hard part is easy deserves a second measurement. The arm is a 13 000 mm²
plate held up by two rails. No orientation was ever going to make that free.

## Summary

| Part | Change | Why |
|---|---|---|
| `02-front-plenum` | upright → **back plate down** | 6 706 mm² beyond 10 mm reach becomes 997 |
| `03-side-fan-arm` | unchanged orientation, **support now documented** | no orientation avoids it |
| everything else | unchanged | measures clean |

Worst unsupported reach on the eight support-free parts is **5.0 mm**, on the top brace.

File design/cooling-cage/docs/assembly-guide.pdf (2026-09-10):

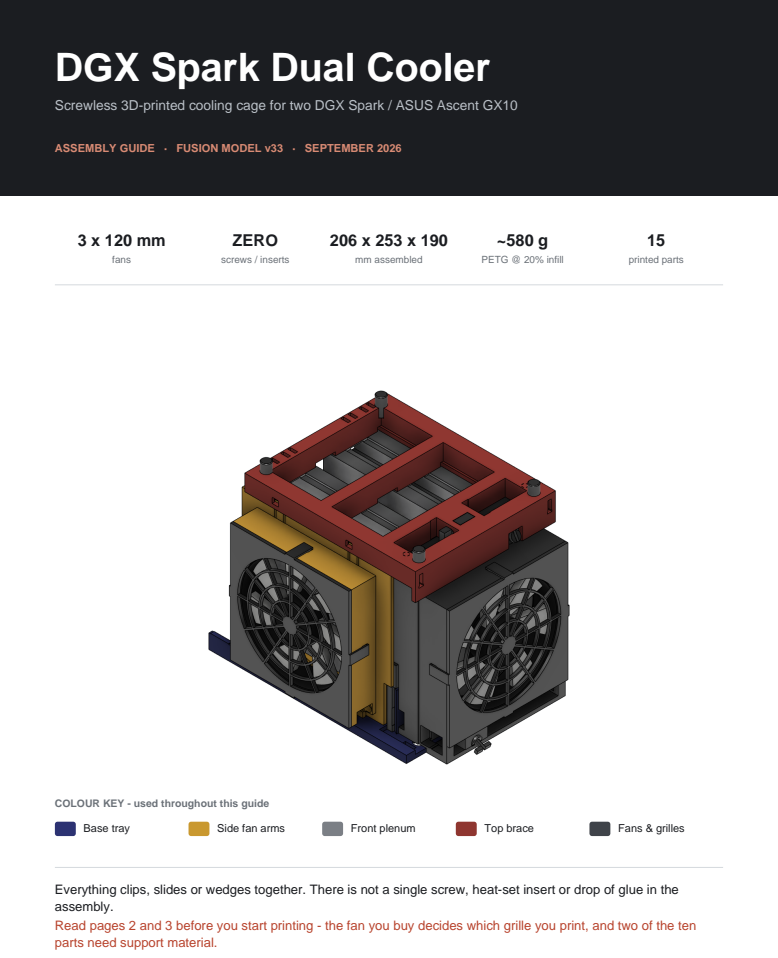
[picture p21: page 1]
screws / inserts; mm assembled; PETG @ 20% infill; printed parts; Base tray; Side fan arms; Front plenum; Top brace; Fans & grilles

DGX Spark Dual Cooler

Screwless 3D-printed cooling cage for two DGX Spark / ASUS Ascent GX10

ASSEMBLY GUIDE · FUSION MODEL v33 · SEPTEMBER 2026

COLOUR KEY - used throughout this guide

Everything clips, slides or wedges together. There is not a single screw, heat-set insert or drop of glue in the
assembly.
Read pages 2 and 3 before you start printing - the fan you buy decides which grille you print, and two of the ten
parts need support material.

BILL OF MATERIALS · PART 1

# What you print

Part | Qty | Size mm | Print orientation | Support | cm3
PRT_01 Base tray | 1 | 176 x 220 x 46 | floor down | none | 205
PRT_02 Front plenum | 1 | 139 x 180 x 66 | back plate down | yes | 284
PRT_03 Side fan arm | 2 | 172 x 166 x 40 | flat, collar up | yes | 122 ea
PRT_04 Top brace | 1 | 156 x 190 x 30 | top face down | none | 240
PRT_05 Fan grille (26 mm fans) | 3 | 135 x 135 x 21 | grille face down | none | 29 ea
PRT_05B Fan grille (25 mm fans) | 3 | 135 x 135 x 21 | grille face down | none | 29 ea
PRT_06 Wedge key | 1 | 10 x 6 x 41 | on edge | none | 1.4
PRT_07 Stacking peg | 4 | dia 10 x 20 | standing | none | 1.6 ea
PRT_08 Button pin, long | 1 | 15 x 31 x 72 | widest face down | none | 1.2
PRT_09 Button pin, short | 1 | 10 x 10 x 45 | oblique | none | 0.6

Every STL and the 3MF is already in its correct orientation, sitting on Z = 0. Drop them in and slice - do not rotate. Print one grille variant only: PRT_05B has 2.2 mm clamp pads for 25 mm fans, PRT_05 has 1.2 mm pads for 26 mm fans.

TWO PARTS NEED SUPPORT
The side fan arm and the front plenum each carry a large flat panel that starts in mid-air, and neither has an orientation that avoids it. Tree supports under the arm plate are enough; the plenum wants normal supports under its front face. The other eight parts print with nothing, worst unsupported reach 5 mm.

PRINT SETTINGS
PETG. Every latch, hook and pin leg is a printed spring.
0.4 mm nozzle, 0.2 mm layers.
4 perimeters minimum - thin walls halve every snap feature. 20 % infill. Nothing is structural beyond the flexures.
No brim needed on any part.

Collar top wall, notched at both ends for the unit feet

PLATE GROUPING - HOW THE 3MF IS LAID OUT

Plate | Contents
1 | Base tray
2 | Front plenum
3 and 4 | Side fan arm, one per plate
5 | Top brace + wedge key + 4 stacking pegs + both button pins
6 to 8 | Fan grille x 3, 25 mm variant (PRT_05B)
9 to 11 | Fan grille x 3, 26 mm variant (PRT_05) - print one set or the other
Standard 3MF has no plate concept, so most slicers open all objects at once in a grid. Use "arrange all" or assign plates by hand from this table. The grilles are 135 mm square, so only one fits a 248 x 250 mm bed at a time.
DGX Spark Dual Cooler · Assembly guide · Fusion model v33 | 2

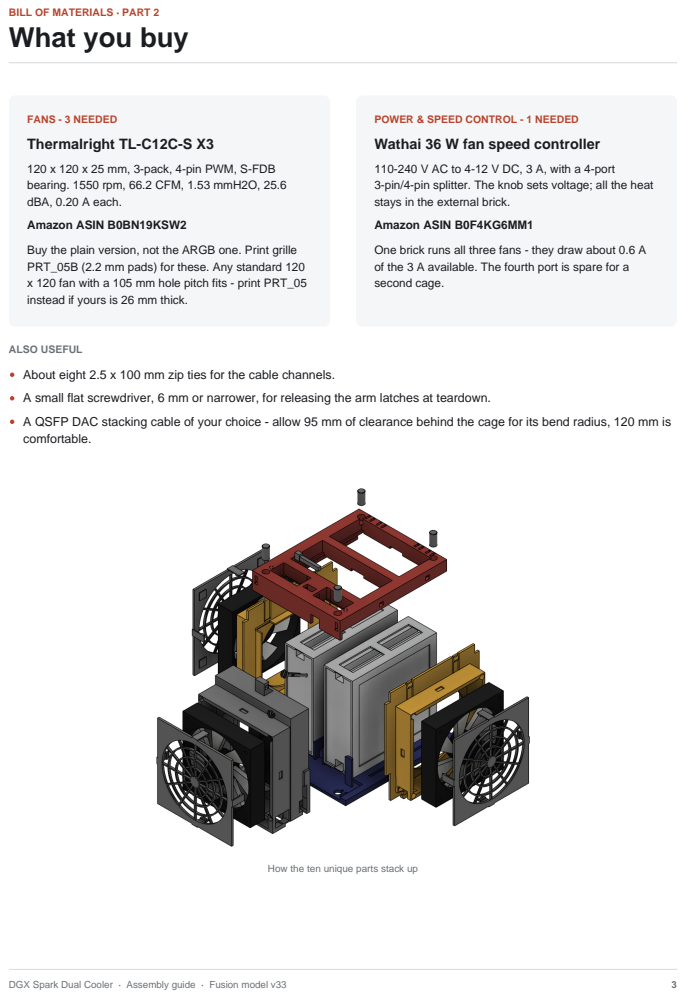
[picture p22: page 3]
FANS - 3 NEEDED Thermalright TL-C12C-S X3

BILL OF MATERIALS · PART 2
What you buy

POWER & SPEED CONTROL - 1 NEEDED
Wathai 36 W fan speed controller

120 x 120 x 25 mm, 3-pack, 4-pin PWM, S-FDB
bearing. 1550 rpm, 66.2 CFM, 1.53 mmH2O, 25.6
dBA, 0.20 A each.
Amazon ASIN B0BN19KSW2
Buy the plain version, not the ARGB one. Print grille
PRT_05B (2.2 mm pads) for these. Any standard 120
x 120 fan with a 105 mm hole pitch fits - print PRT_05
instead if yours is 26 mm thick.

110-240 V AC to 4-12 V DC, 3 A, with a 4-port
3-pin/4-pin splitter. The knob sets voltage; all the heat
stays in the external brick.
Amazon ASIN B0F4KG6MM1
One brick runs all three fans - they draw about 0.6 A
of the 3 A available. The fourth port is spare for a
second cage.

ALSO USEFUL
About eight 2.5 x 100 mm zip ties for the cable channels.
A small flat screwdriver, 6 mm or narrower, for releasing the arm latches at teardown.
A QSFP DAC stacking cable of your choice - allow 95 mm of clearance behind the cage for its bend radius, 120 mm is
comfortable.

How the ten unique parts stack up

READ THIS ONCE BEFORE ASSEMBLING

# How it holds together

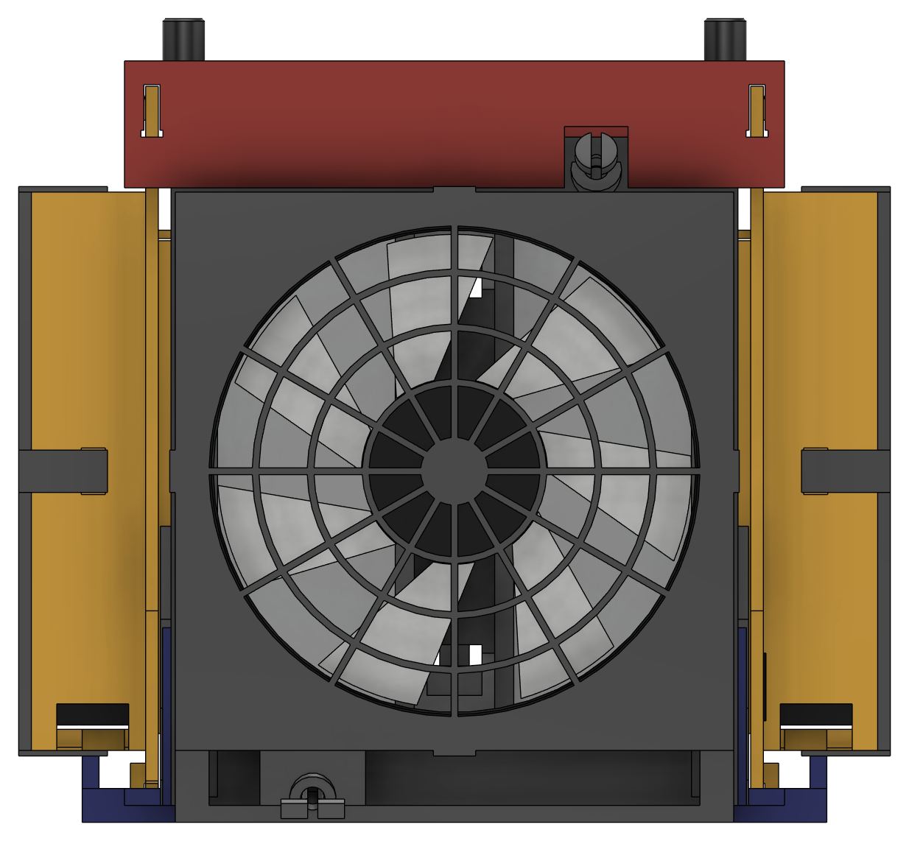
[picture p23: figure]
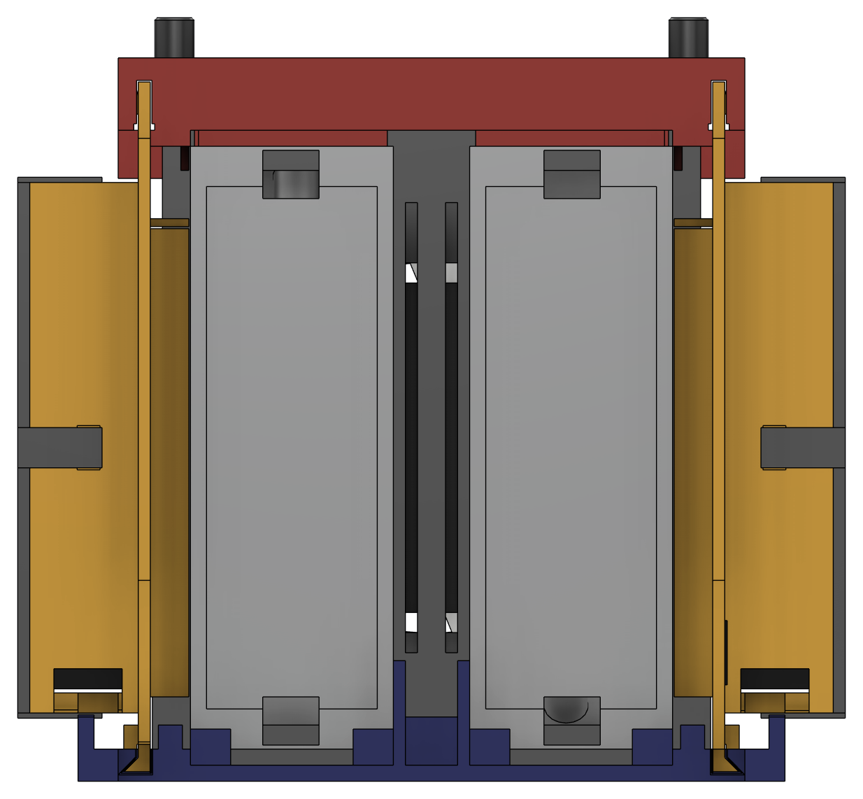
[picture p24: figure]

FRONT - intake, front fan, both button pins | REAR - ports, QSFP cable, exhaust, glands
The two units are MIRRORED. One is flipped end-for-end so that both filtered bottom panels face outward into the side fans. A consequence is that one unit's power button sits near the top of the front face and the other near the bottom -which is why there are two different button pins.
Air path: each side fan blows inward through the unit's filtered bottom panel; the front fan pressurises a sealed plenum that feeds both front intakes, plus a centre duct that jets air down the 19 mm gap between the units. Everything exhausts rearward, and the rear is left deliberately clear.

THE FIVE THINGS THAT HOLD IT TOGETHER

Joint | Mechanism | Numbers
Arm to tray | 45 deg half-dovetail, slides in from the rear | 0.12 mm clearance, 150 mm travel
Arm to brace | Two cantilever latch barbs into catch pockets | 4.6 N to release, 0.90 mm engagement
Grille to collar | Four cantilever hooks over four notches | 2.8 N per hook, ~11 N to click on
Plenum to brace | Tusk tenon through a mortise, wedge key | 0.65 mm of taper to tighten
Button pin to tube | Split shaft, two spring legs, snap barb | 0.45 mm squeeze of 1.20 available

BEFORE YOU START
Work on a clear bench with the tray front edge toward you, and keep the two arms identified - they are the same printed part used twice, the second one rotated 180 degrees. Nothing in this build needs force beyond a firm push; if a part will not go, something is the wrong way round.

STEPS 1 AND 2

# Assembly

## 1 Set down the base tray

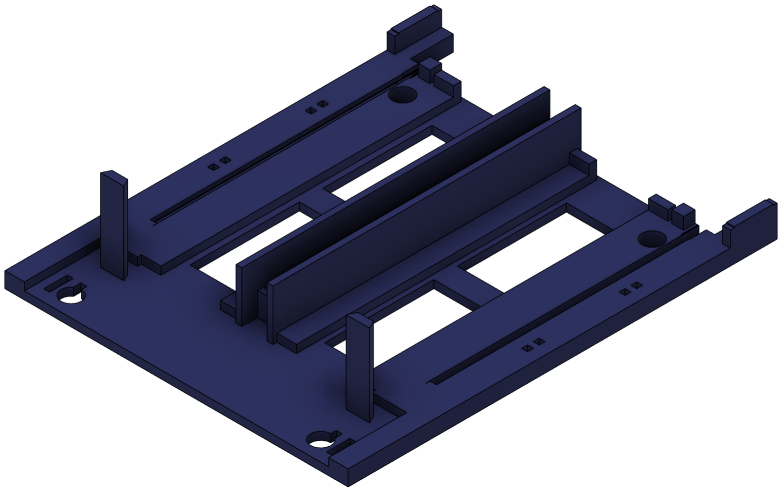
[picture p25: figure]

Put the tray on the desk with the front edge - the end carrying the two dovetail posts - toward you. Every other part locates off this one, so get it square and leave clearance behind it.
The rear end is the one with the wide side ears and the two cable glands.
Nothing is fixed to the desk. The cage simply sits on the tray floor.

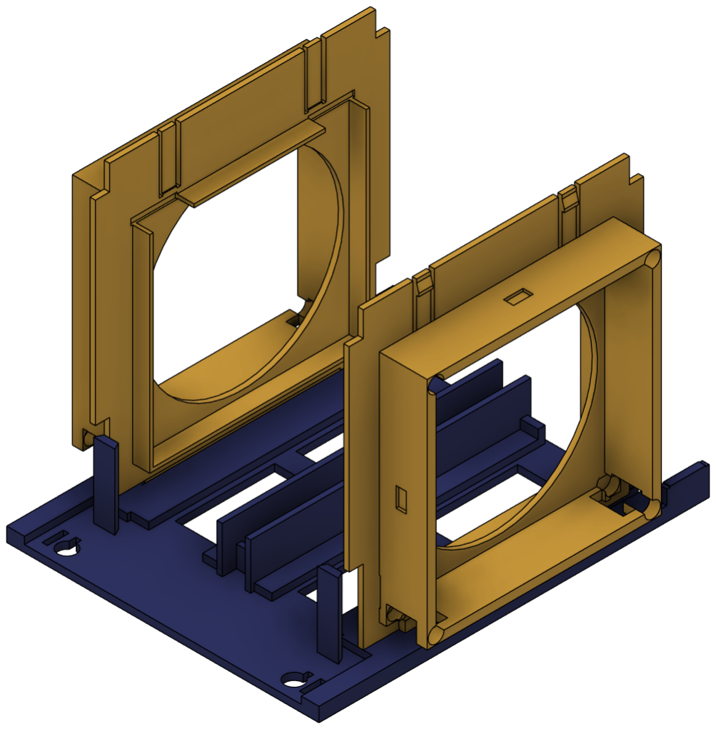
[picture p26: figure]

## 2 Slide in the two side fan arms

Both arms are the same printed part, the second one rotated 180 degrees. Start each arm at the REAR of the tray with its dovetail tongue in the slot, then slide it forward about 150 mm until it hits the hard stop.
The clearance is 0.12 mm per flank - it should slide with light thumb pressure and no rattle.
Keep the rear ears clear: anything on them taller than 17 mm blocks the arms.

STEPS 3 AND 4

# Assembly

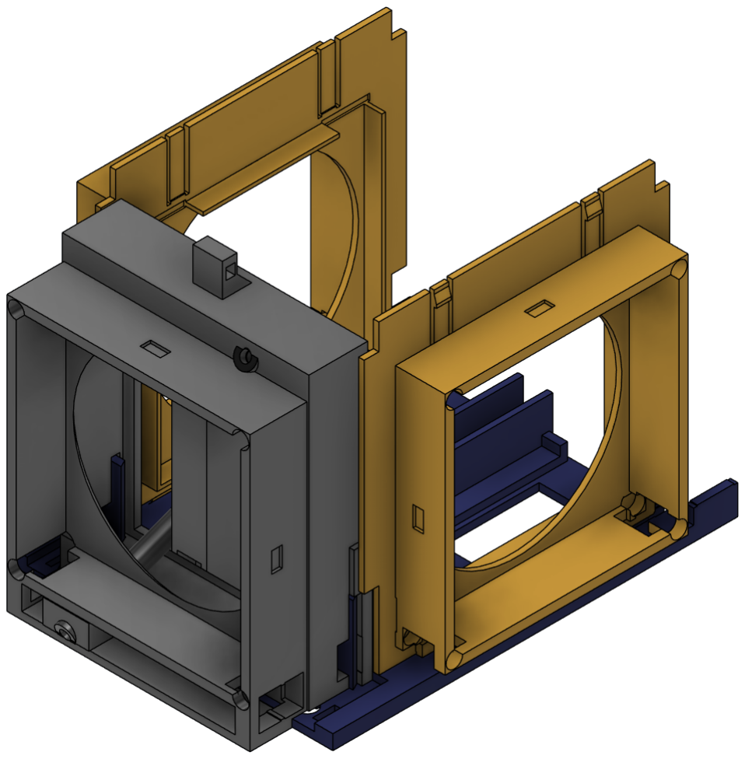
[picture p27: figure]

## 3 Drop the front plenum on

Lower the plenum straight down over the two dovetail posts at the front of the tray. It engages only one way round. The last 40 mm should drop under its own weight.
The dovetails lock it fore-aft and side-to-side; the brace will stop it lifting.
The two round tube ends visible inside are the power-button pin guides.

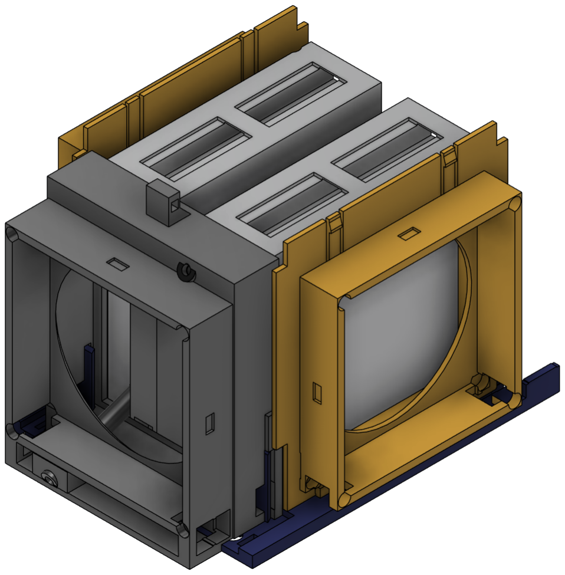
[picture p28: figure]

## 4 Lower in the two units

Stand each unit on edge and lower it into its cradle. The second unit goes in flipped end-for-end, so that both filtered bottom panels face outward toward the side fans.
Connect the QSFP stacking cable now - it is far easier before the brace goes on.
The units are held inboard by the tray centre wall and outboard by the arm collar, leaving 0.40 mm of play.

STEPS 5 AND 6

# Assembly

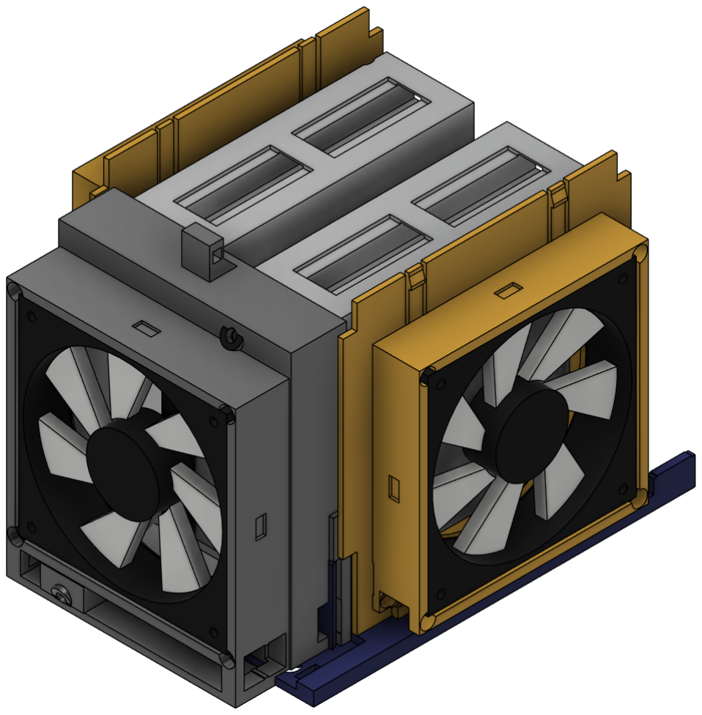
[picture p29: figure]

## 5 Push in the three fans

Each fan pushes into its collar from the outside and seats on the round sealing land at the bottom of the pocket. Check the arrow on the fan frame: both side fans must blow INWARD, and the front fan must blow toward the rear.
Drop the lead into whichever corner channel it lands nearest - all four corners are relieved, so any rotation works.
The fan sits about 1 mm proud of the collar face. The grille takes up that gap.

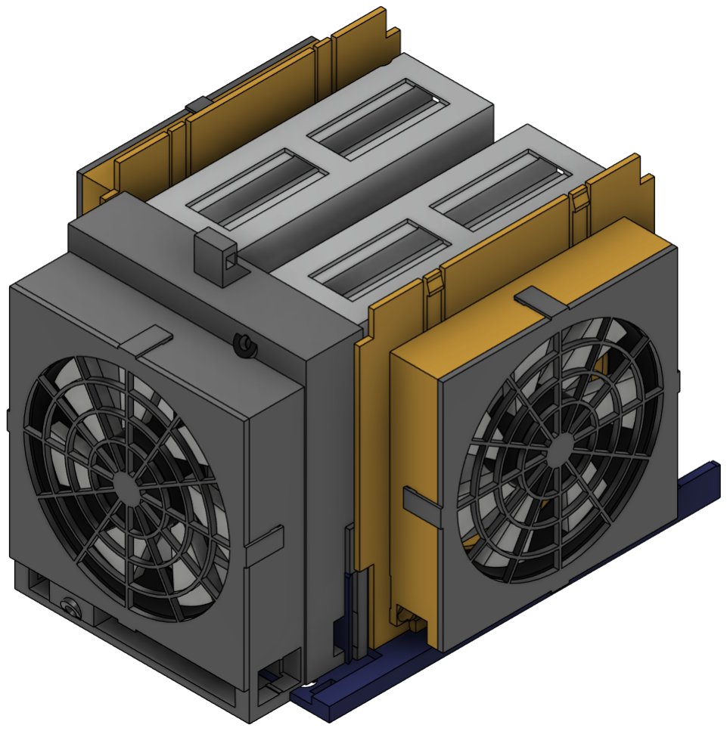
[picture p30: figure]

## 6 Clip on the three grilles

Line each grille up so its four hooks sit over the four notches, then press evenly until all four click - about 11 N. Check the variant matches your fan thickness before you push.
PRT_05B for 25 mm fans, PRT_05 for 26 mm. The wrong one leaves the fan loose and buzzing.
To swap a fan later, pry off that grille only. Nothing else comes apart.

STEPS 7 AND 8

# Assembly

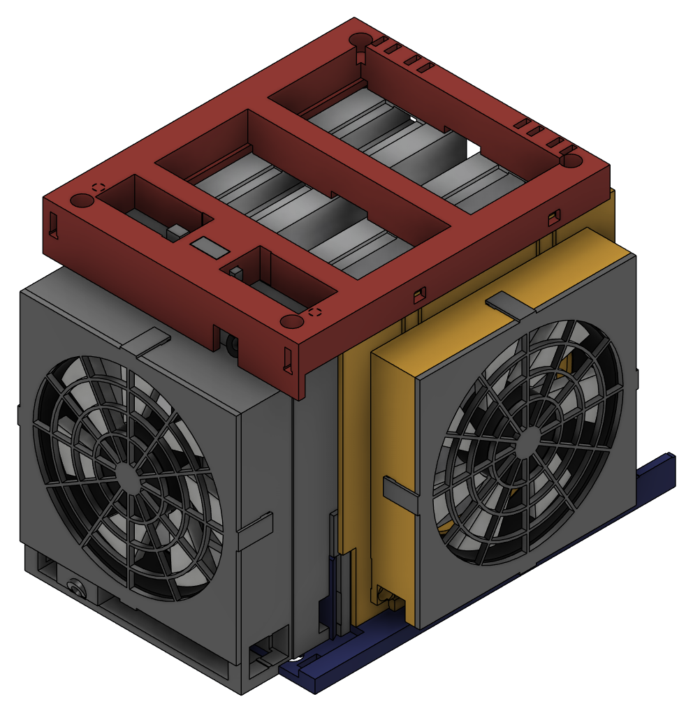
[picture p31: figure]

## 7 Fit the top brace, then the wedge key

Lower the brace straight down. The tops of both arms enter the grooves in its underside, and about 5 mm from home the two latch barbs cam over and snap into their catches. Then slide the wedge key in from the left, through the bridge and the plenum tenon, and tap it home.
The key is the only thing resembling a fastener in the build. It locks the brace to the plenum.
It has 0.65 mm of taper, so tap it a little further if the joint ever feels slack.

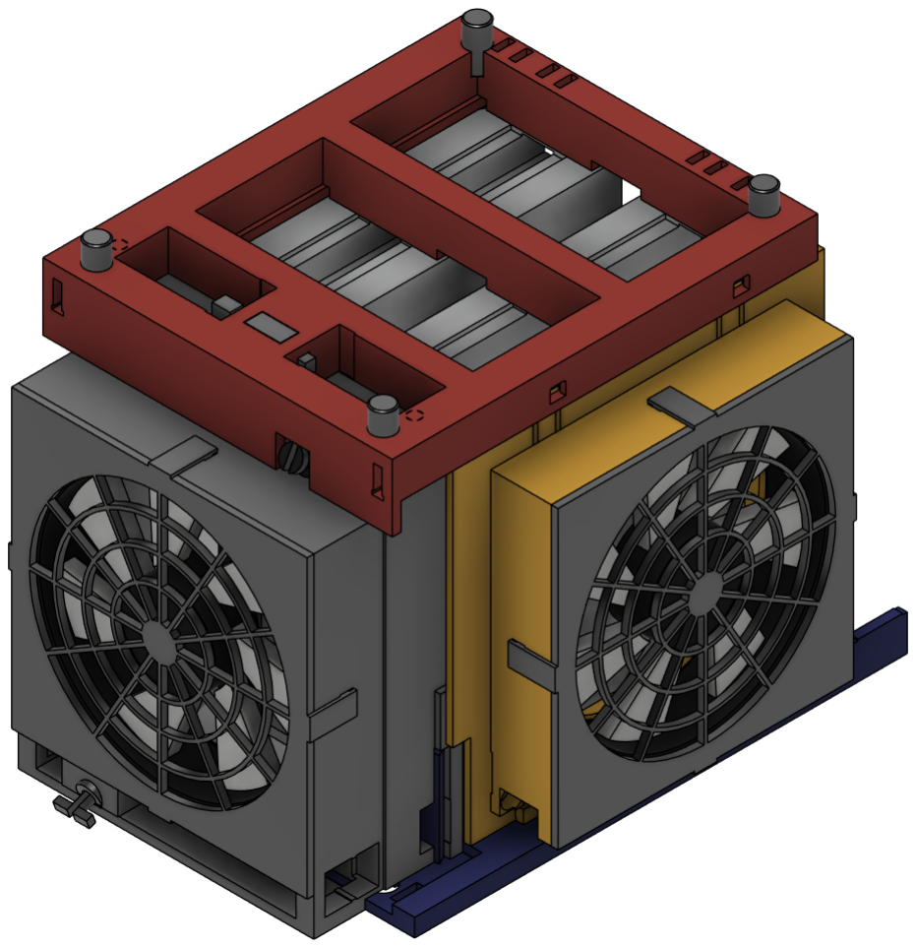
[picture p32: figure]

## 8 Pegs and button pins

Press the four stacking pegs into the top of the brace, then snap each button pin into its guide tube from the front. The long pin serves the unit whose button is high, the short one the unit whose button is low.
Each pin needs about 0.45 mm of leg squeeze to pass the mouth, and is captive once in.
To release an arm latch at teardown, push the flat pad square through the window in the brace with a 6 mm blade - about 4.6 N.

EVERY LEAD IS CHANNELLED, AND EXITS AT THE BACK

# Routing the fan leads

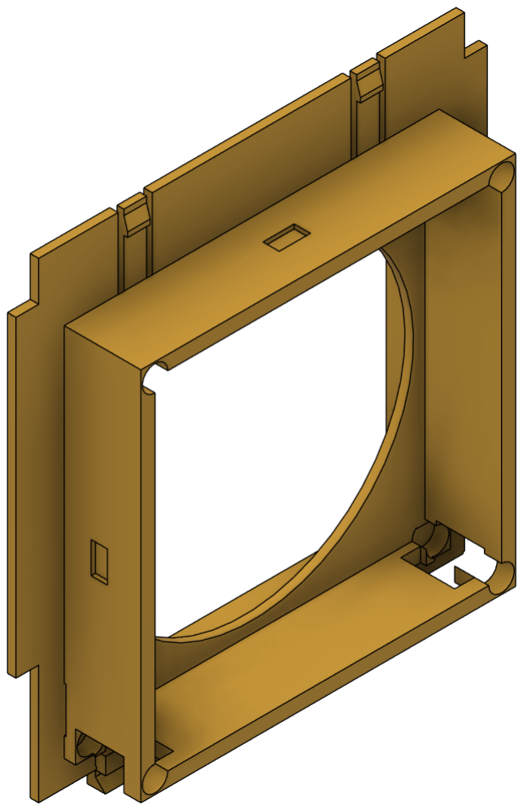
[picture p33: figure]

COLLAR - relieved corners and the floor exit | UNDERSIDE - floor exits and the run to the rear
All three fan leads run inside the cage and come out together at the rear, where the brick and splitter sit. Nothing crosses the rear ports and nothing sits in the hot exhaust - the run is entirely outboard of the exhaust footprint and below the port strip.

Side fans: the lead drops down whichever pocket corner it sits in, through the floor exit, into the tunnel between the tray ear and the underside of the arm collar.
Front fan: the lead leaves through a side window in the plenum skirt and joins the same tunnel.
Both then run rearward through the gland and out of the back of the tray. Zip-tie the bundle at the gland so nothing can creep back into a fan.

Every restriction on the route clears a 14 x 8 mm fan connector: arm cable windows 16.5 x 10.0 mm, plenum skirt windows 21.5 x 10.0 mm per side, plenum rear slot 10.5 x 16.5 mm per side, fan-pocket floor slots 15.5 mm on the arm and 14.3 mm on the plenum.

FINISHING UP

# Power, first run and service

WIRING
Plug all three fans into the 4-port splitter. The fans are 4-pin PWM but the controller sets speed by voltage - the PWM line simply floats, which is fine.
Splitter into the 4-12 V brick, brick into the wall. Keep the brick outside the cage; all of its heat stays in the brick, which is the whole reason for choosing it.

SETTING THE SPEED
Start the knob at minimum and wind it up. Below roughly 5 V the fans may not spin up at all - that is normal for voltage control, not a fault.
Three fans draw about 0.6 A of the available 3 A, so the fourth port is free for a second cage.

SERVICE
Swapping a fan: pry off that grille only, everything else stays together.
Full teardown: drive the wedge key out, release both arm latches through the brace windows, lift the brace, then reverse the build.
The arms slide out to the rear. Do not lift a unit out before the brace is off - the capture ribs straddle its top edge.

IF YOU HAVE ARMS FROM AN EARLIER RELEASE
The GX10 has four rubber feet on its bottom panel, and that panel is the face looking out into the side fan, so the feet land on the shroud collar. Arms printed from the current files are already notched to clear them. On older arms, cut the collar
top wall away from each corner to the far edge of the latch snap, both sides, both ends, both arms.

WHAT IS NOT PROVEN YET
Nothing since the first build has been printed. Every figure in this guide is measured from the solid model, not from a part in hand.
The centre duct is a calculated design. Its two exit slots are tapeable, so an A/B test is easy - tape them, run the same load, compare.
Latch, hook and pin-leg stiffness are calculated, not measured.

DGX Spark Dual Cooling Cage by koldfrontier, licensed CC BY 4.0 https://github.com/koldfrontier/dgx-spark-ops
Models are CC BY 4.0; documentation and code are Apache-2.0. Use, remix and sell derivatives freely - just credit the source.

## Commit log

2026-08-24 Add DGX Spark dual cooling cage design
    Screwless 3D-printed cooling cage for two DGX Spark / ASUS Ascent GX10
    units with three 120 mm fans (front + both sides).
    Contents under design/cooling-cage:
    - cad/ Fusion 360 .f3d source and neutral STEP export
    - print/ 3MF with all 10 printable parts laid out across plates,
    plus individual pre-oriented STLs for Thingiverse / MakerWorld
    - docs/ illustrated assembly guide (PDF) and design notes
    - images/ renders used in the guide and listings
    Design is fully screwless: dovetails, snap hooks and a wedge key.
    No part requires support; widest bridge span is 12.8 mm.
    Licensed CC BY 4.0.
    [01-base-tray.stl, 02-front-plenum.stl, 03-side-fan-arm.stl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]
2026-09-10 Cage v3: foot-clearance notches, corrected support claims, full re-export
    The GX10's four rubber feet land on the shroud collar - the panel they sit
    on is the face that looks out into the side fan. The reference model has no
    feet, so interference analysis never saw it. The collar top wall is now cut
    away at both ends, leaving material only over y 38.0-112.0, mirrored about
    y = 75 so both arms clear at both ends.
    Re-measuring printability while verifying that cut turned up a second
    problem: the claim that no part needs support does not hold for the two
    large parts.
    - The side fan arm is a 166 x 172 mm plate 3 mm thick carried by two narrow
    rails. Since the v2 shroud collar it cannot sit o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
    [01-base-tray.stl, 02-front-plenum.stl, 03-side-fan-arm.stl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]
2026-09-10 Fix the exploded view: fans and grilles belong outboard of the arms
    The side fans nest inside the arm (x 73-99 within the arm 60.4-100) and the
    grilles cap them from outside (82-103); the front fan and grille sit the same
    way relative to the plenum. The exploded render pulled the arms and the plenum
    out but left the fans and grilles where they were, so each fan read as sitting
    inboard of its arm - the reverse of how it goes together.
    Each part now moves along its own assembly direction, so the stack reads
    outward as unit, arm, fan, grille, and forward as plenum, fan, grille.
    assembly-guide.pdf rebuilt around the corrected render (page 3).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
2026-09-14 Add the four-Spark switchless-ring DeepSeek-V4.1-Flash recipe and ring-ops notes
    New `recipes/DeepSeek-V4.1-Flash-Quad-DGX-Sparks`: one vLLM TP4 endpoint across
    four GB10 units cabled as a ring, no switch. Launcher driven by a ring.conf that
    holds every per-machine value, a cluster script that gets the start/stop order
    right, four boot profiles (eager gate, 300K serving, fair-prefill, 1M context),
    and verification scripts that catch the failures this stack has which look like
    a healthy container. Measured: 62-63 ms decode step, C1 57.2 / C6 151.9,
    needle exact at 298K/596K/993K tokens, 829-request soak with zero errors.
    New `notes/ring-ops.md`: verifying the transport by RDMA counters rathe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
2026-09-14 Quad recipe: boot 6 (Engram fast staging, 128 read threads, 500K) and the speed-run disposition; ring notes: channel count, the one-shot all-reduce as the switch's tok/s case
    tonyd2wild's 2026-09-14 speed-run levers measured on a native checkpoint on
    the ring: Engram fast staging + 128 threads give cold prefill +16..48% at
    3-50K, unchanged at 130K, -7% at 300K, decode unchanged, C6 152; the
    NCCL 8-channel change is neutral on the cycle and reverted; the b12x
    one-shot RoCE all-reduce cannot run on a ring and is the first concrete
    decode number a switch would buy. New profiles/boot6-engram-fast-500k.env.
2026-10-03 Add the three-Spark GLM-5.3-Flash TensorFold recipe and the GB10 re-cabling bandwidth note
    Three GX10s as a switchless triangle on MiaAI-Lab's TensorFold recipe (v1.4,
    three-Spark engine): fabric addressing, a fabric health check, measured start
    settings (COMM=roce, NCCL_CHANNELS=8), the harness and its results.
    notes/gb10-cx7-hotplug-ltr.md: a GB10 whose ConnectX-7 is hot-re-added after
    both QSFP cages were empty runs RDMA at ~1/8 speed (loopback 14 vs 107 Gb/s)
    until reboot; the root ports' LTR bit is the marker. Measured, with the method.
    Tuning re-run on the healthy fabric in progress.
2026-10-30 Add the Swift 1.5 IQ3_S on one Tesla V100 recipe (Strata, 262K, not a Spark)
    One Tesla V100-PCIE-32GB with 2x Xeon Gold 6138 and 192 GB RAM, Strata 0.1.52 built for sm_70. The serving form
    measured fastest there:
    - PR #3411's 13 Volta environment switches (+8.6-10.5% decode at 32K, output byte-identical);
    - --kv-resident 32768 (what setup writes from 64K up; +20-36% at 262K over a hand-edited config without it);
    - one slot (a second slot added no throughput on this card).
    Decode 88-93 tok/s code at up to 128K; sanity 12/12.
    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
2026-11-07 V100 recipe: current hardware notes (fan floors 65/65, turbo uncapped, iommu=pt) and what the box serves now
    - Hardware notes: the freeze fix is the BIOS idle fan floors (50/50 passed a 30-minute combined burn, 65/65 since
    2026-10-31, no freeze since); the 2.7 GHz cap is removed, and the uncapped benchmark rerun matched the capped runs.
    Adds iommu=pt (pinned copies 7.3 -> 12.3 GB/s), hp-wmi-sensors, the riser CPU note and the V100 under a 250 W burn.
    - Status: the box serves plain Qwen3.8-Flash-Next IQ3_S in the same S1 form, with tool-call recovery and pictures
    through the CPU vision reader, and its measured decode.

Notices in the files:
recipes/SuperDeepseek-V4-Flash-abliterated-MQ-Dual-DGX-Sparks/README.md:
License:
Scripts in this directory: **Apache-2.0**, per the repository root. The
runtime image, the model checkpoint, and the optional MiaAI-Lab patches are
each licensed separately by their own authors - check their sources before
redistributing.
